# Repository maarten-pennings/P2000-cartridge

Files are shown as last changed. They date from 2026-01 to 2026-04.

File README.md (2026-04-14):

# P2000-cartridge

Making a cartridge for the Philips P2000T.

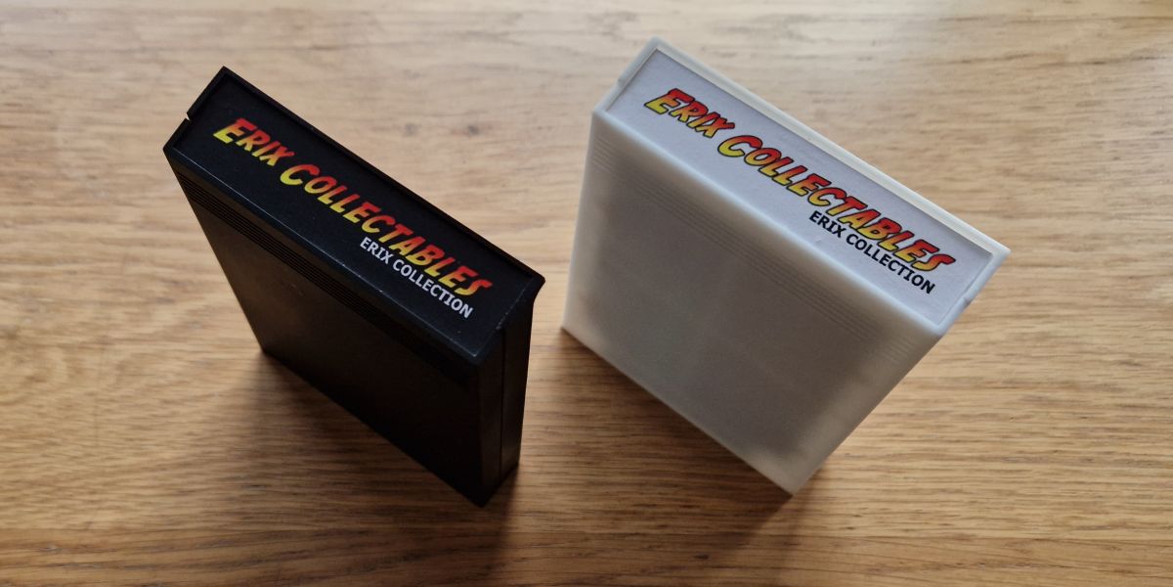
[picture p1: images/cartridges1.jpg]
Cartrdiges


## Introduction

Since I retrieved an old [Philips P2000](https://github.com/maarten-pennings/P2000) from my attic I wanted to make a cartridge myself. 
I help repairing retro computers at [Erix Collectables](https://www.erixcollectables.nl/), and also there we planned 
making a cartridge to facilitate testing and bringing up P2000 mods.

## Analysis

I did some [analysis](analysis.md) coming to the following conclusions:

- Ivo Filot ([Github](https://github.com/ifilot) or [blog](https://philips-p2000t.nl/)) uses
  the [SST39SF0x0](SST39SF010A-SST39SF020A-SST39SF040-Data-Sheet-DS20005022.pdf), 
  it is one of the cheaper solutions, and we have a programmer for it. 
  We will also pick this memory.
- Let's make a modest multi-rom: SST39SF010 - 1 Mbit or 128 kbyte or 8 ROMs. 
  But let's prepare the PCB that they work for the bigger chips too.
- Use PLCC socket; it is smaller than DIL/DIP.
- No reset switch - we don't need it.

## Design

With the analysis phase done, let's make the [PCB](pcb.md).
Design it, manufacture it, test it (tracks), assemble it, and test functionality.
 
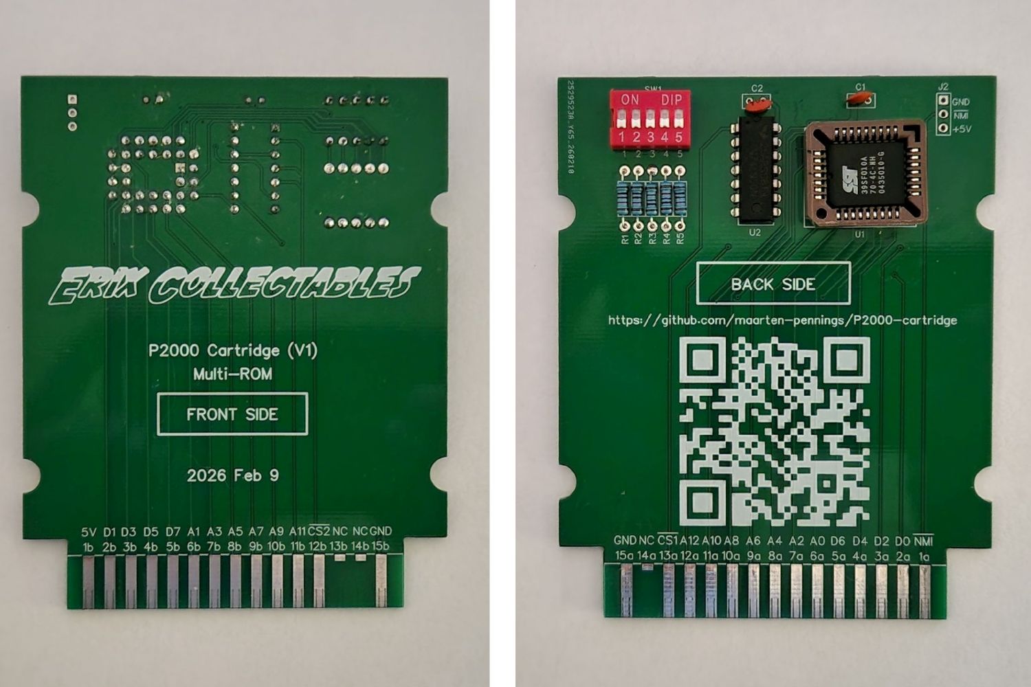
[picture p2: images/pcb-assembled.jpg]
PCB assembled

 
Find all design files (schematics, layout, gerber) in the [pcb](pcb) directory.
.

## Selecting ROMs

Which ROMs to put on the multi-ROM cartridge?
The chosen flash chip 39SF010 has room for 8.

### Stock cartridges

Likely cartridge images are:

- (0) A self-made table of [Contents](roms/myroms).  
  You can press any key to get some references.
- (1) [BASIC NL 1.1](https://github.com/p2000t/software/blob/main/cartridges/BASICNL1.1.bin).  
  The [User manual](https://github.com/p2000t/documentation/blob/main/programming/Gebruiksaanwijzing%20P2000T%20met%20P2305%20Basic%20NL.pdf) is available.
- (2) [Forth](https://github.com/p2000t/software/blob/main/cartridges/Forth.bin).  
  The [User manual](https://github.com/p2000t/documentation/blob/main/programming/Forth30.pdf) or maybe
  the [older version](https://github.com/p2000t/documentation/blob/main/programming/Forth12.pdf).
- (3) [UCSD Pascal](https://github.com/p2000t/software/blob/main/cartridges/UCSD%20Pascal.bin).  
  No documentation. Needs floppy?.
- (4) [Assembler](https://github.com/p2000t/software/blob/main/cartridges/assembler%205.9.bin).  
  No documentation.
- (5) [JWS Disk BASIC](https://github.com/p2000t/software/blob/main/cartridges/JWSBasic.bin).  
  For a P2000 with built-in JWS drive.
  It seems this was developed by Jan-Willem Sparnaaij to enable floppy disks instead of the cassette recorder in BASIC.
  Lot of [tape (?) software](https://github.com/p2000t/software/tree/main/cassettes/JWS).
  The [User manual](https://github.com/p2000t/documentation/blob/main/software/JWS.pdf).
- (6) [ECOL](https://github.com/p2000t/software/blob/main/cartridges/ECOL3.0.bin).  
  The Educational COmputer Language, tagged `FTU/OC ECOL 3.0`.
  This seems to be a sort of simplified Dutch Pascal (?). The only two commands that do
  something are `datum` (irrespective of casing) and `edit`. The `:-` key on the numeric board toggles capslock.
  I wonder if it needs to be accompanied by a tape with an editor, because `edit` complains `Verkeerde band`.
- (7) [Maintenance 2](https://github.com/p2000t/software/blob/main/cartridges/Maintenance%202.bin).  
  A test cartridge. See the Cartridge User Manual in the [Field Support Manual](https://github.com/p2000t/documentation/blob/main/hardware/FieldSupportManual-2.pdf) page 7.1 (72).
  Maybe also the [Maintenance manual](https://github.com/p2000t/documentation/blob/main/hardware/Maintenance.pdf).

List of candidate cartridges can be found on the 
[P2000T Preservation Project](https://github.com/p2000t/software/tree/main/cartridges).

The ones listed here are ["backed up"](roms/stockroms) in this repo.

### Own cartridge: Contents

The proposal is that the first ROM is a table of contents.
I made the [Contents](roms/myroms) ROM myself. 
It is written in assembler, but rather simple: just an LDIR to copy a screen image to the frame buffer.
Press any key to get some references (URLs).

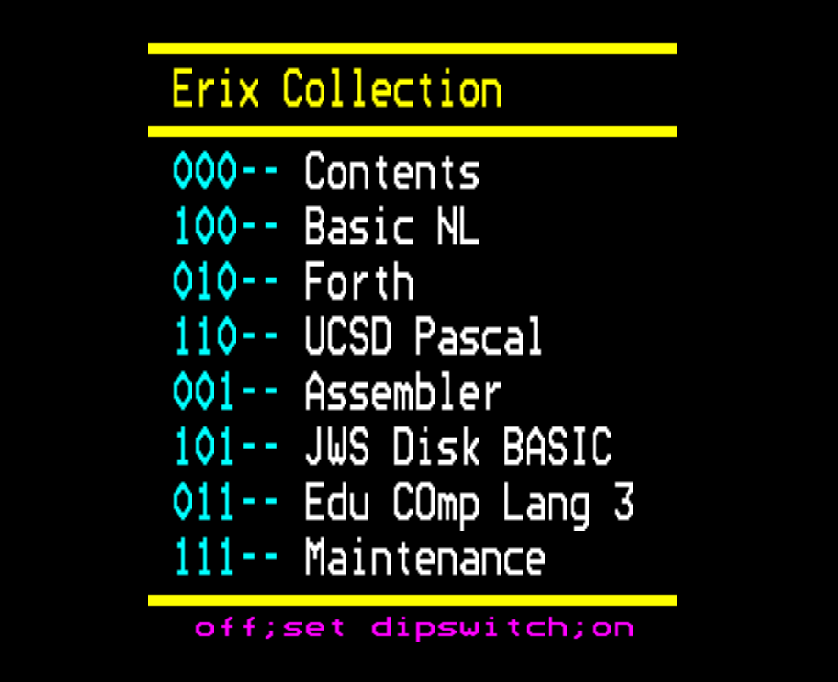
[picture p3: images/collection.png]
Screenshot Collection


### Makefile

The [roms](roms) directory contains a sub directory with the 
[stockroms](roms/stockroms) and a sub directory with [myroms](roms/myroms) 
(the Contents rom). It also contains a [Makefile](roms/Makefile) to compile 
myroms to a `.bin` and convert all `.bin` files (from myroms and from 
stockroms) to flash scripts (`.afp`) - see next section.

## Sub-project: Flash Programmer

We need some tool to flash the `.bin` files to the 39SF0x0 chip.
I don't have one, I could buy one, borrow one or make one.
I went for the latter option an made the "Arduino Flash Programmer".
This topic is described in the [flasher](flasher) directory.

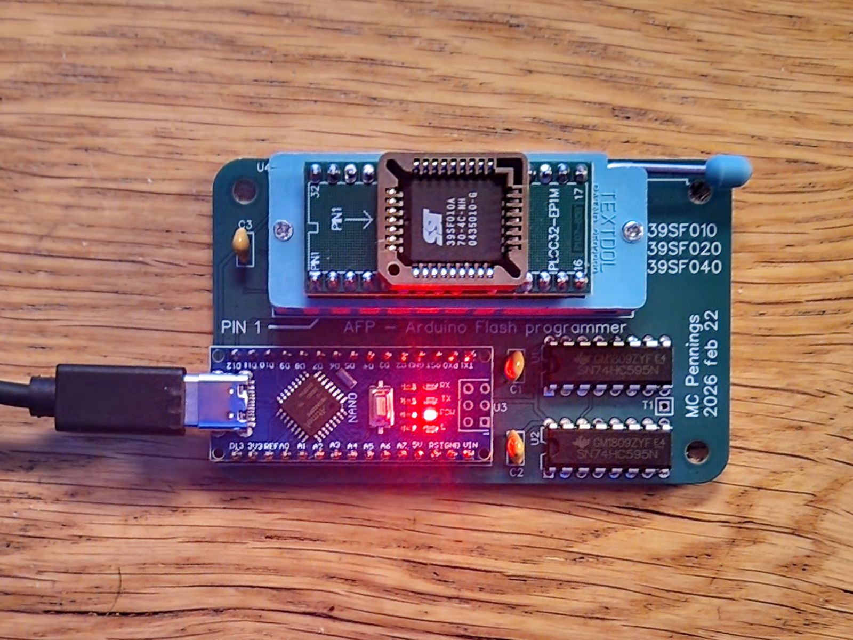
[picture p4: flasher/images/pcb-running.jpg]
AFP


## Casing

One of the last steps is to create a casing.
I wanted it to look as close as possible to the originals.
However, the flash chip in its socket is too high to fit in the original case.
So my case is 1.5mm thicker.
And I have a hole for the dipswitch.

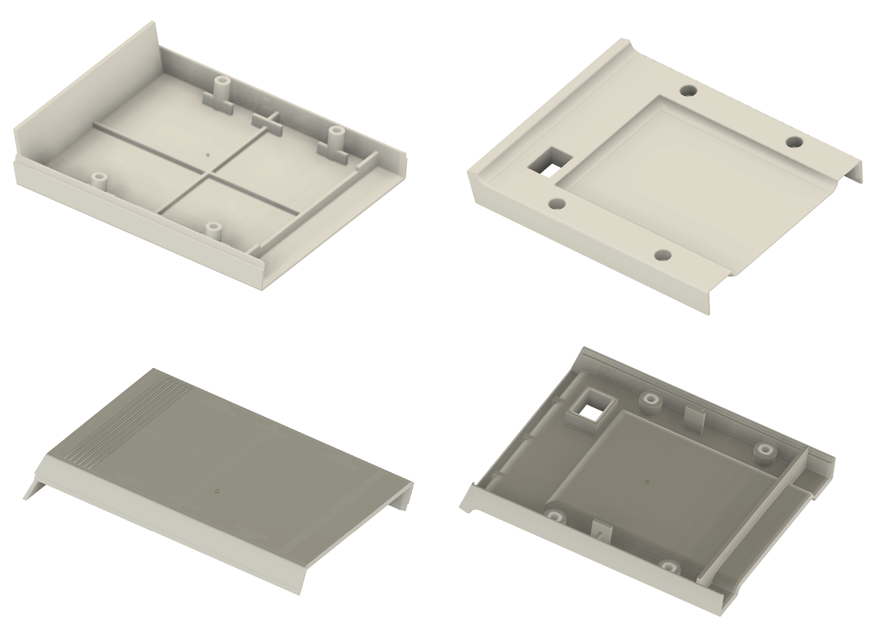
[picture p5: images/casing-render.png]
Casing render
.

I did a 3D print myself. Here mine (left) compared to an original (right).

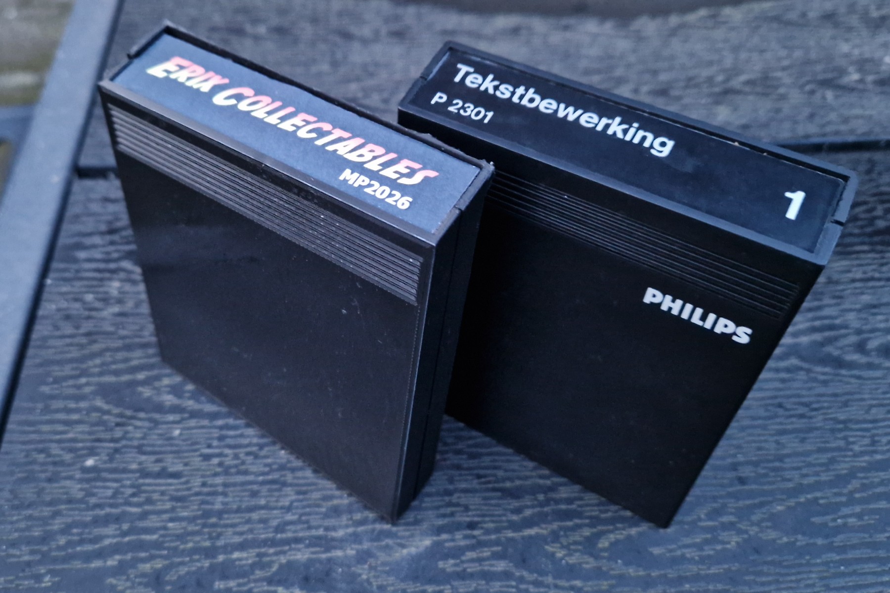
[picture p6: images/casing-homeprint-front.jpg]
Casing home print (front)


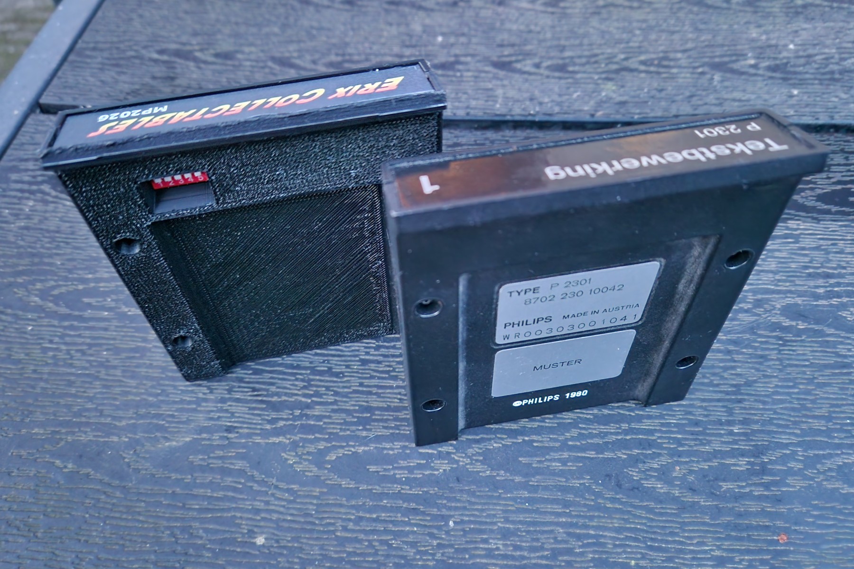
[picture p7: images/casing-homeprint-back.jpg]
Casing home print (back)


Find the stl files in the [case](case) sub directory.

The directory also contains labels: [black](case/label-ErixCollectables-black.png) 
and [white](label-ErixCollectables-white.png) and [sheet](label-ErixCollectables-print.docx).

I also did a 3D print via JLCPCB in white and black.
Those are more detailed with no "support-artifacts".

Cartridges SLA)

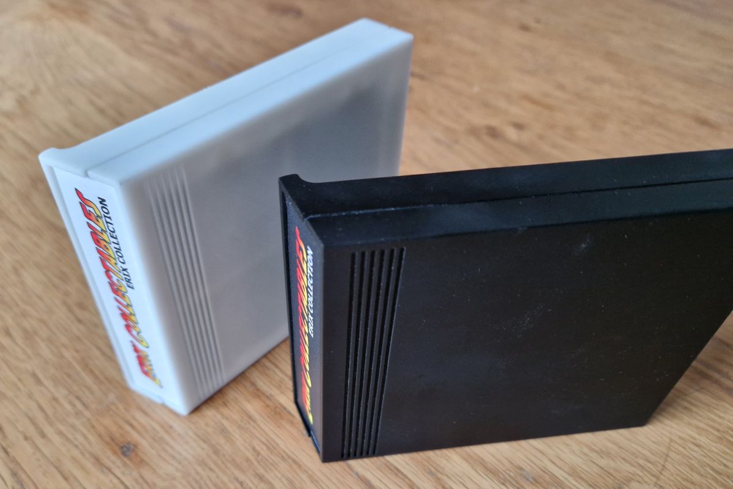
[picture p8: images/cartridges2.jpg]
Cartridges SLA)


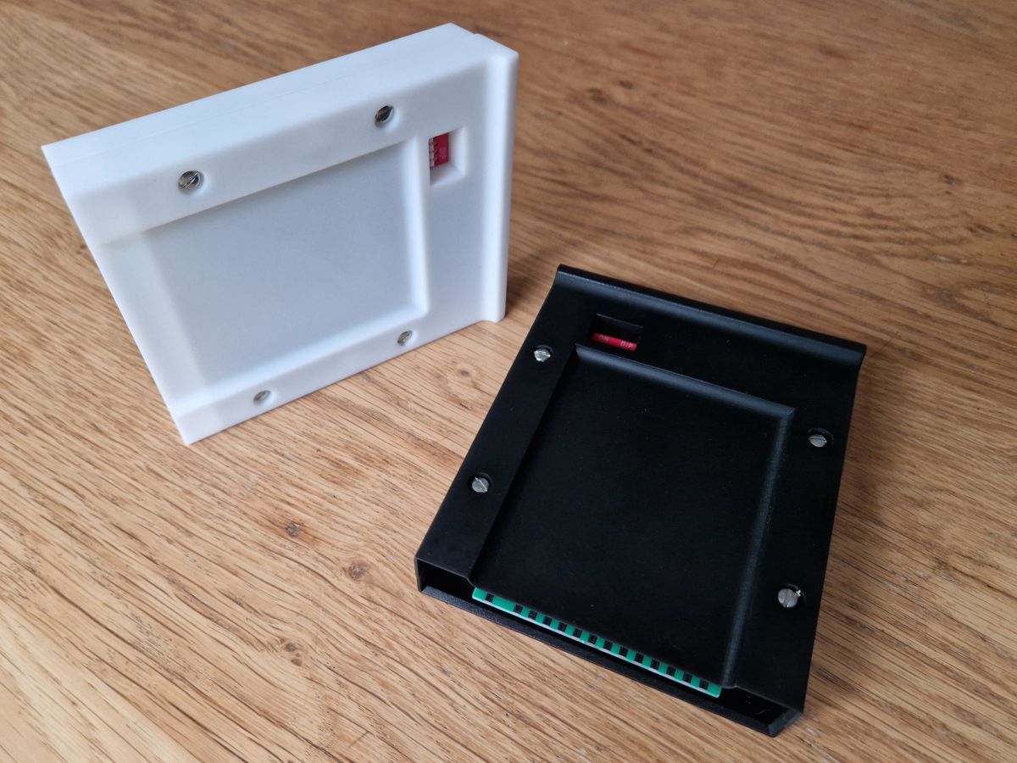
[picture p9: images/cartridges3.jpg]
Cartridges SLA)


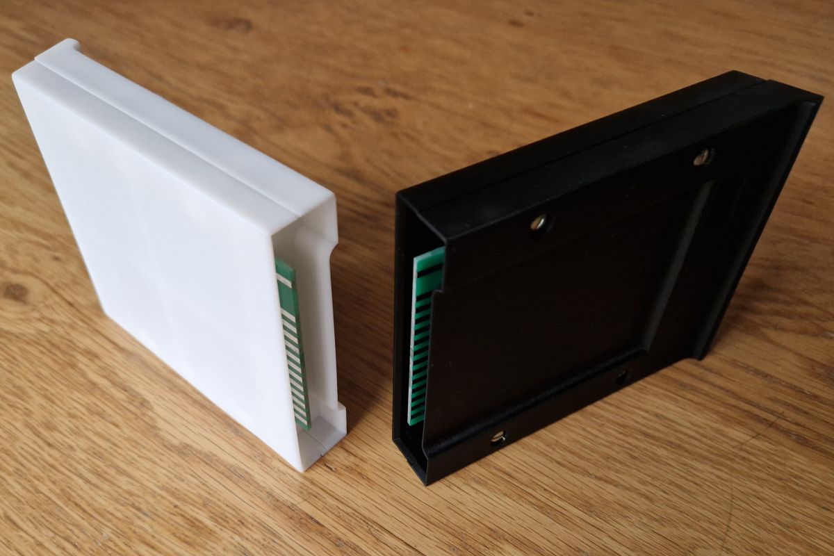
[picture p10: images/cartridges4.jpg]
Cartridges SLA)


## Cost 

Overview of the [cost](cost.md).

(end)

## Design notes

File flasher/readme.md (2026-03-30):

# AFP - Arduino Flash Programmer

Making a tool to program a flash memory.
We use an Arduino Nano with two shift registers to make
the _Arduino Flash Programmer_.

## Prototype

The concept is inspired by [slu4coder's project on GitHub](https://github.com/slu4coder/SST39SF010-FLASH-Programmer).
This is my version of the schematics.

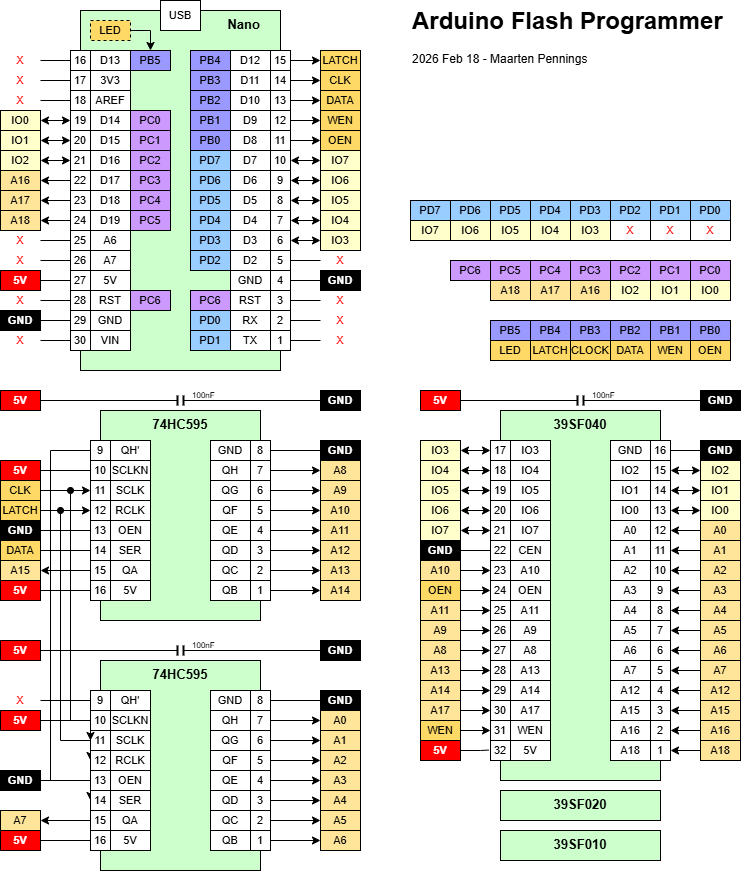
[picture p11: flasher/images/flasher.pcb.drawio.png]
AFP schematics


I tested this on a breadboard

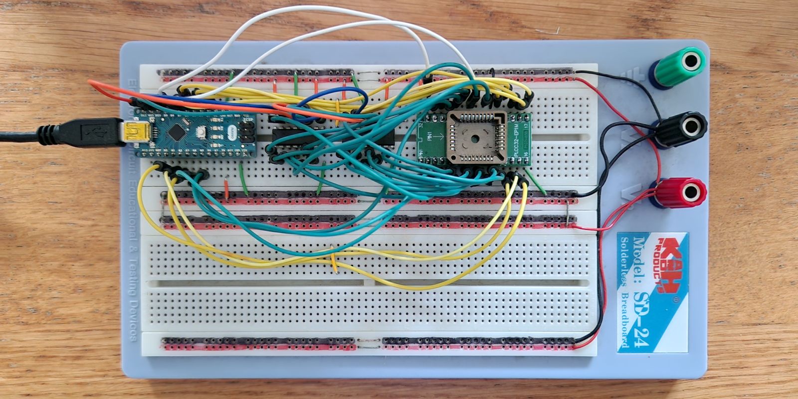
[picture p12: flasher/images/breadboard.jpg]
AFP on breadboard


I quickly found out that I need a tool to get the flash chip 
out of its socket.

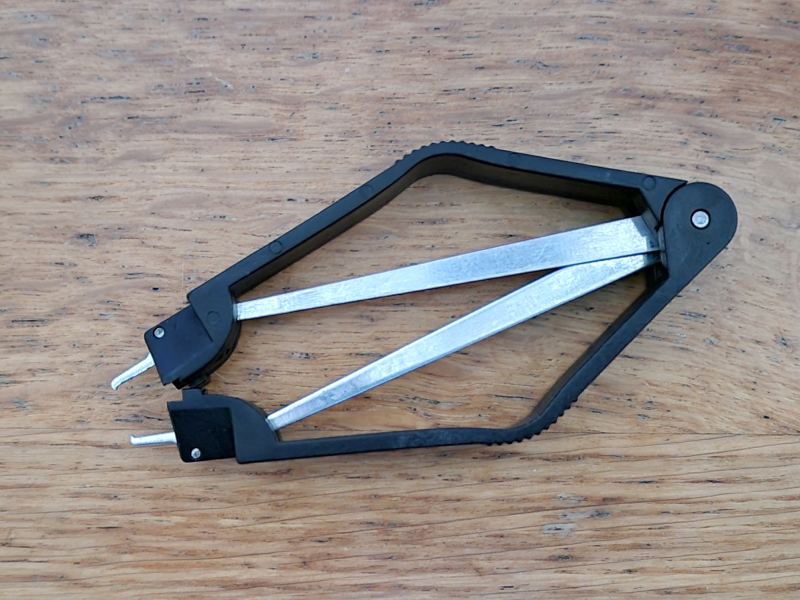
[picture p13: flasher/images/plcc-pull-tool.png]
PLCC IC pull tool


## AFP PCB 

All design files for the PCB are stored in the [pcb](pcb) directory.

### Schematics

I designed the PCB schematics in [EasyEda](https://easyeda.com).
The schematics are available in [pdf](pcb/AFP-schem.pdf) and 
as EasyEda [json](pcb/AFP-schem.json) source.

### Layout

Also the PCB layout I did in [EasyEda](https://easyeda.com).
The layout is available as two pdfs [front](pcb/AFP-pcb-front.pdf) and [back](pcb/AFP-pcb-back.pdf),
and also as EasyEda [json](pcb/AFP-pcb.json) source.

### Gerber

For ordering at [jlcpcb](https://jlcpcb.com) I created a gerber file.
The final [gerber](pcb/AFP-gerber.zip) is also available in this repo.

### PCB render 

The render of the PCB.

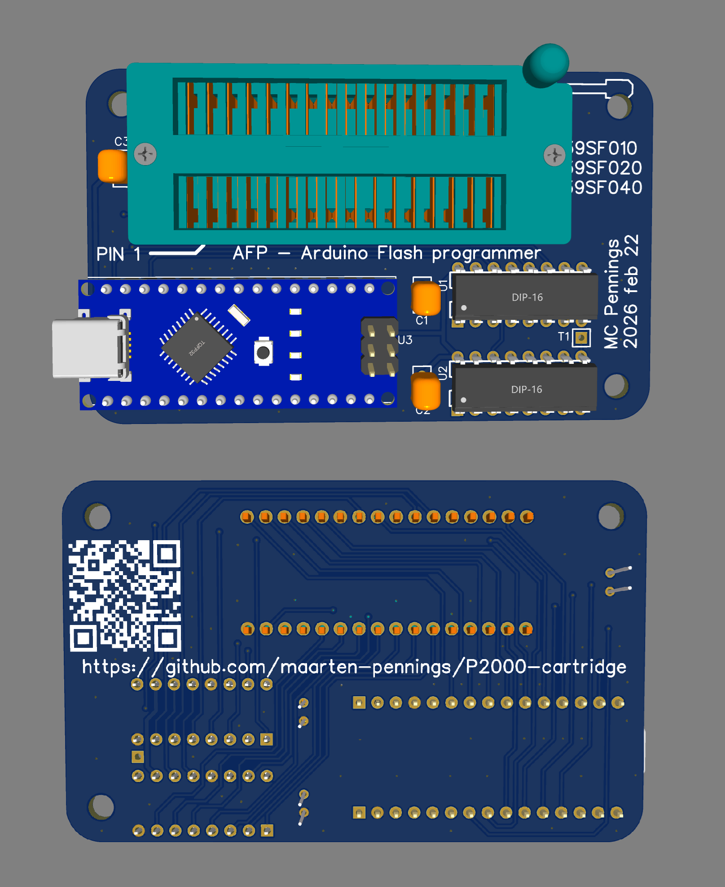
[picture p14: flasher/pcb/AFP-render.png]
PCB render


### PCBs

I ordered at 2026-02-22 and 2026-03-04 the PCBs arrived at my home.

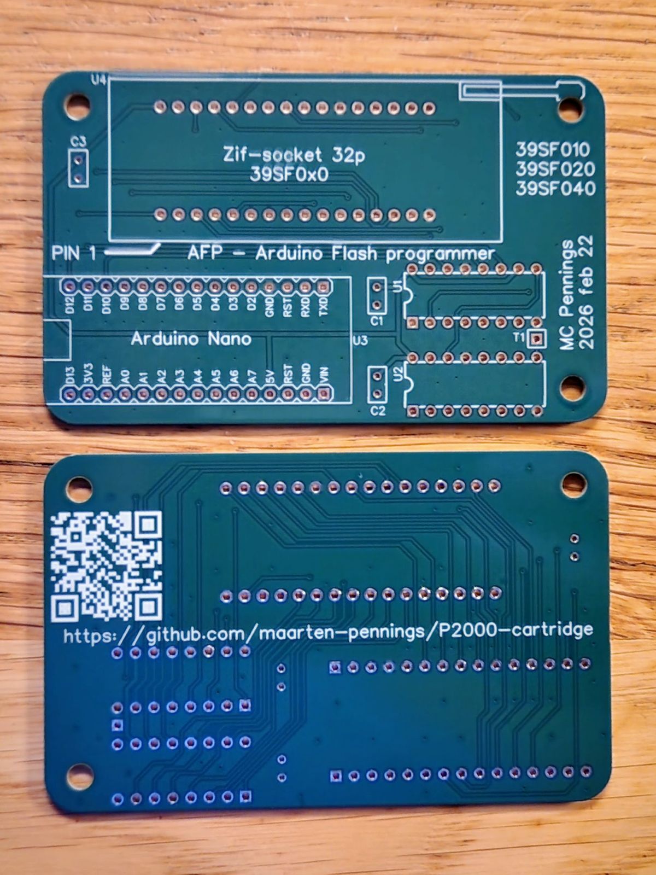
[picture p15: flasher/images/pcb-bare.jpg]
Bare PCB


### Assembly 

After mounting the two ICs, 3 caps, the Arduino Nano and ZIF socket,
the PCB was ready.

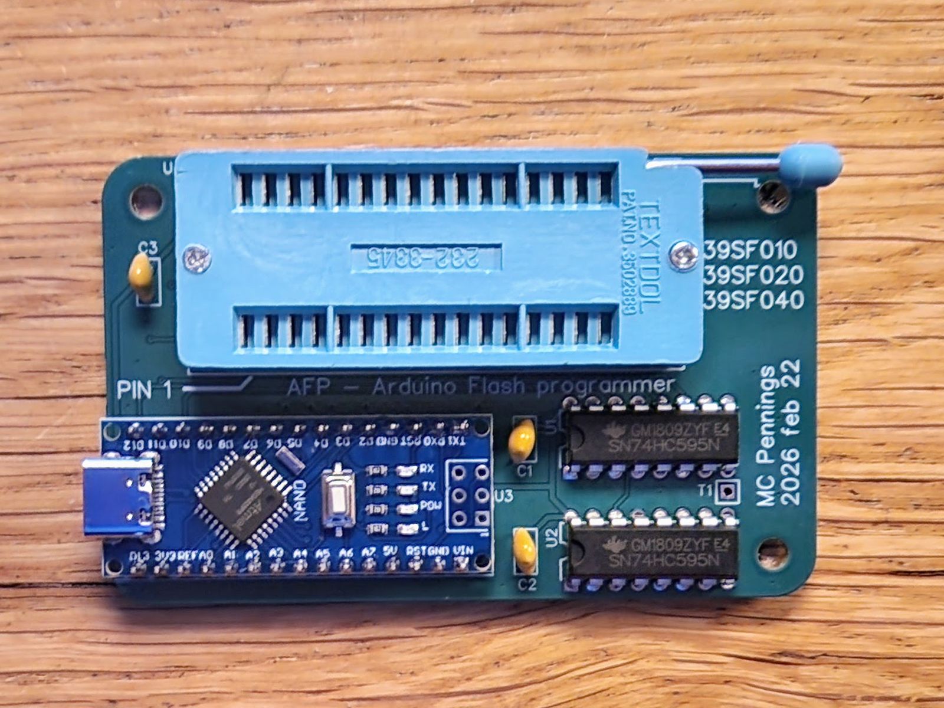
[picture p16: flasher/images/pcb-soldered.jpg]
Soldered PCB


### Firmware

The [AFP firmware](afp) shall be compiled with the 
[Arduino IDE](https://www.arduino.cc/en/software)
and flashed to the Nano.

### Final product

I use an adapter board (here mounted in the ZIF socket) to convert DIL to PLCC.
The adapter board itself contains the PLCC socket (here filled with an 39SF010.

Running PCB

## AFP Manual

Once the firmware is flashed and the AFP connected to a PC, 
a terminal program needs to be started. Make sure to select 
the correct COM port (see e.g. Device Manager), and configure
the terminal program for 115200,8N1. You could use the 
terminal program built into Arduino.

You should be welcomed with the following banner.

```
      _       ________  _______
     / \     |_   __  ||_   __ \
    / _ \      | |_ \_|  | |__) |
   / ___ \     |  _|     |  ___/
 _/ /   \ \_  _| |_     _| |_
|____| |____||_____|   |_____|
Arduino Flash Programmer - version 1.0a

drv  : init
cmd  : init
cmds : init

Type 'help' for help
>> 
```

The `>>` is the prompt of AFP. 

### help

As suggested, we can type `help` to get a list of commands.

```
>> help
Available commands
echo - echo a message (or en/disables echoing)
erase - erase (sector of) the flash
flash - view and control flash size
help - gives help (try 'help help')
info - application and cpu info
read - read flash contents
write - write bytes to flash
```

Help on help explains that commands and sub commands may be shortened.

```
>> help help
SYNTAX: help
- lists all commands
SYNTAX: help <cmd>
- gives detailed help on command <cmd>
NOTES:
- all commands may be shortened, for example 'help', 'hel', 'he', 'h'
- all sub commands may be shortened, for example 'help help' to 'help h'
- normal prompt is >>, other prompt indicates streaming mode
- commands may be suffixed with a comment starting with //
- some commands support a @ as prefix; it suppresses output of that command
```

### echo and info

The `echo` command prints user supplied messages back. 
Give `help echo` if you want to know details.
We skip it here.

Another command we do not further discuss is `info`.

```
>> info
name   : Arduino Flash Programmer
version: 1.0b
author : Maarten Pennings
date   : 2026 mar 20
voltage: 4634 mV
cpufreq: 16000000 Hz
uartbuf: 64 bytes
```

### erase 

A more interesting command is `erase`.
Note that for safety reasons this can not be shortened.

```
>> help erase
SYNTAX: erase
- shows which sectors are empty or in use
SYNTAX: erase <addr>
- erases (ie fill with 0xFF) the sector indicated by <addr>
- when <addr> has form 'all', the whole chip (all sectors) is erased
- when <addr> has form 's<hex>' (sector) that sector is erased
- when <addr> has form 'r<hex>' (rom) all sectors of that rom are erased
NOTE:
- <hex> is in hex
- a sector (4096 bytes) is the unit of erase of the flash chip
- a rom consists of <rom> sectors, the unit of use (eg ROM cartridge)
- <rom> is set with the 'flash' command
- for added safety 'erase' command can not be abbreviated
```

It allows us to pass what to erase: typically a sector (4 kbyte),
or a "rom" (a group of 4 sectors), or "all" sectors. 

Note that the term _erase_ in the context of flash memories writes 0xFF 
to all locations in one _sector_. That is typical for flash memories: erase 
is per sector. Once a sector is erased to 0xFF, writes to bytes 
are allowed; they can only change 1's to 0's.

A nice feature of the `erase` command is to run it without arguments, it
then lists which sectors are "empty", that is, (still) 
completely filled with 0xFF.

If we run this on a memory already programmed with "our" 
stock image, we get this overview.

```
>> erase
rom sectors addresses    state-of-sectors:empty/inuse
R00 S00-S03 00000-03fff:  inuse    -      -      -  
R01 S04-S07 04000-07fff:  inuse  inuse  inuse  inuse
R02 S08-S0b 08000-0bfff:  inuse  inuse  inuse    -  
R03 S0c-S0f 0c000-0ffff:  inuse  inuse  inuse  inuse
R04 S10-S13 10000-13fff:  inuse  inuse  inuse  inuse
R05 S14-S17 14000-17fff:  inuse  inuse  inuse  inuse
R06 S18-S1b 18000-1bfff:  inuse  inuse  inuse  inuse
R07 S1c-S1f 1c000-1ffff:  inuse  inuse  inuse  inuse
clusters: empty 4 inuse 28
```

This tells us that rom 0 (sectors 0-3) contains a small program
(max 4k): the upper 3 sectors are still empty.

It also tells us that the third rom (sectors 8, 9, 10 and 11) 
only uses 3 sectors, not 4.

### flash

The AFP (firmware and PCB) supports three memory chips: 
39SF010 (128k), 39SF020 (256k) and 39SF040 (512k).
They have the same footprint, the smaller chips just 
ignore 2 or 1 address line.

With the flash command, we tell AFP what we use.
There is an auto detect.

```
>> flash chip auto
manid BF: Microchip/SST
devid B5: 39SF010 (1 Mbit = 128 kbyte)
chip size: 128 kbyte (32 sectors) (8 roms)
``` 

This command also allows setting the "rom" size.
This is a pure _software_ feature. 
All addresses entered are either a hex number (actual address), 
or an `S` followed by a hex number (the hex number is the sector number, 
the actual address is found by multiplying by 4k), or an 
`R` followed by a hex number (the hex number is the rom number).
How many sectors a rom is can be set with `flash rom`.

```
>> flash rom 16
rom  size: 16 kbyte (4 sectors)
```

Here we set it to 16 kbytes, the size of P2000 ROMs.
This happens to be the default of AFP anyhow.

### read

The read command needs a starting address and a size.
As starting address we can pass an address, sector number,
or rom number.

The following reads target the same address with these three options.

```
>> read r3 20
R03 S0c 0c000: 5c 00 00 00 00 00 00 00  00 00 00 00 00 00 00 e9
R03 S0c 0c010: 18 4d 0c 00 5e 14 0d 81  00 00 00 00 00 00 00 00
>> read s0c 20
R03 S0c 0c000: 5c 00 00 00 00 00 00 00  00 00 00 00 00 00 00 e9
R03 S0c 0c010: 18 4d 0c 00 5e 14 0d 81  00 00 00 00 00 00 00 00
>> read c000 20
R03 S0c 0c000: 5c 00 00 00 00 00 00 00  00 00 00 00 00 00 00 e9
R03 S0c 0c010: 18 4d 0c 00 5e 14 0d 81  00 00 00 00 00 00 00 00
```

When not specifying the size, a whole "page" is printed (256 bytes).
When not specifying an address the read continues 
where the previous read stopped.

### write

After `erase` the most important command is `write`.
We pass it an address (again three flavors are supported:
address, sector, rom) followed by the data bytes. This command 
supports streaming mode: by passing `*` as data byte streaming 
mode is toggled. When streaming mode is enabled, an end of line 
(new line) does not terminate the write command. It just continues 
on the next line, the streaming prompt will show the address.

As a non-typical example see streaming mode in action.

```
>> read s3 20
R00 S03 03000: ff ff ff ff ff ff ff ff  ff ff ff ff ff ff ff ff
R00 S03 03010: ff ff ff ff ff ff ff ff  ff ff ff ff ff ff ff ff
>> write s3 11 22 33 * 44
w03004>> 55 66 
w03006>> 77 * 88
>> read s3 20
R00 S03 03000: 11 22 33 44 55 66 77 88  ff ff ff ff ff ff ff ff
R00 S03 03010: ff ff ff ff ff ff ff ff  ff ff ff ff ff ff ff ff
```

For a more typical example of streaming mode see the afp files 
generated by the [Makefile](../roms/Makefile).
You can find afp files by going to 
[GitHub actions dashboard](https://github.com/maarten-pennings/P2000-cartridge/actions) 
click top one, and on the next screen at the bottom, download and open the build results 
called "roms.zip".

It might be good to know that the write command maintains 
error statistics. These can be reset.

```
>> write stats clear
cleared
>> write s3 aa bb
>> write stats
bytes written 2
write errors  2
elapsed time  25342 ms
```

Both write fail because sector s3 was just written with 
`11 22`, so a write of `aa bb` without an erase fails.

## Script

In the sub-directory [roms](../roms) you find all the roms 
(binary files), and (Python) programs that result in a script
(sequence of write commands) for the AFP tool.

There are several tools in the flow:

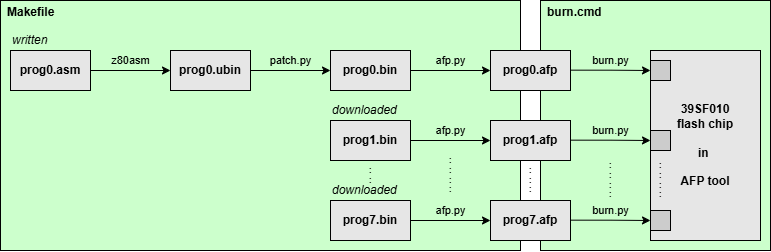
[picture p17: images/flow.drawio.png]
Flow overview


## Test rig

One out of the 10 cartridges I made is not working.
It is cartridge nr 9; when I plug it into a P2000 it is not recognized by the P2000.
The P2000 behaves as if no cartridge is plugged in, which is probably concluded when the chcecksum has a mismatch.
I swapped the 39SF010 memory chip with another cartridge, but nr 9 keeps failing (and the other cartridge kept working), so the PCB seems to be the issue.

I bought an edge connector and hooked it up to an Arduino.
Basically I made a test rig with an architecture similar to the AFP board design.
I read the ROM from cartridge 9 and this proved ok (read back what I flashed).

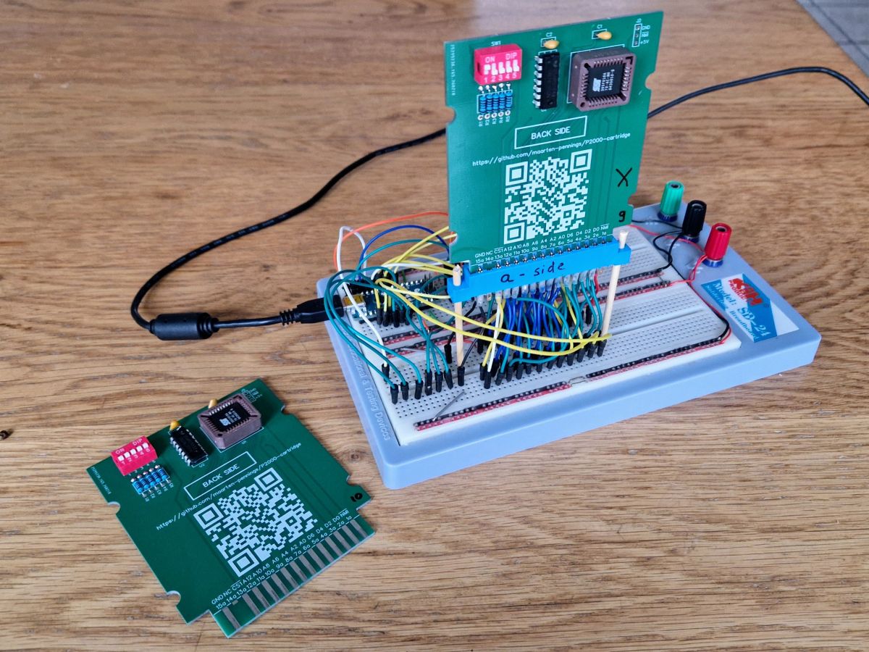
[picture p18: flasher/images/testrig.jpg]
Test rig


I'm puzzled why the PCB is not working.

(end)

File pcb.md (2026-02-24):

# P2000-cartridge - PCB design

With the analysis phase done, let's make the PCB.
Design it, manufacture it, assemble it, and test it.

## Schematics

I designed the PCB schematics in [EasyEda](https://easyeda.com).
They are available in [pdf](pcb/P2000Cartridge-schem.pdf) and 
as EasyEda [json](pcb/P2000Cartridge-schem.json) source.

## Layout

Also the PCB layout I did in [EasyEda](https://easyeda.com).
The layout is available as two pdfs [front](pcb/P2000Cartridge-pcb-front.pdf) 
and [back](pcb/P2000Cartridge-pcb-back.pdf),
and also as EasyEda [json](pcb/P2000Cartridge-pcb.json) source.

I double checked the socket since I don't have it yet physically.
Warning, the socket diagram is the pin-out from the front side of the PCB 
("bottom view").

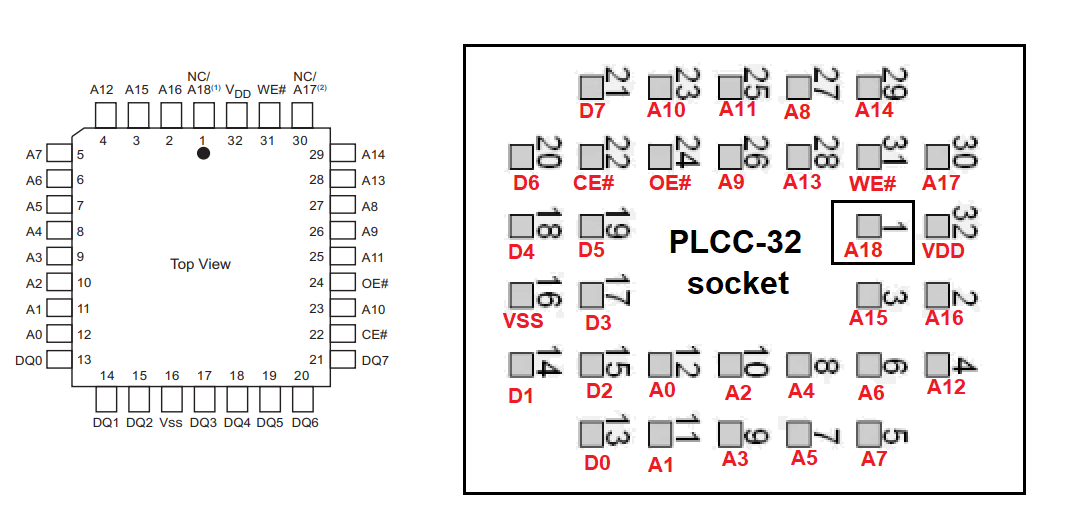
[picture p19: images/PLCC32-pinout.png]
socket
 

## Gerber

For ordering at [jlcpcb](https://jlcpcb.com) I created a gerber file.
The final [gerber](pcb/P2000Cartridge-gerber.zip) is also available in this repo.

The render of the PCB.

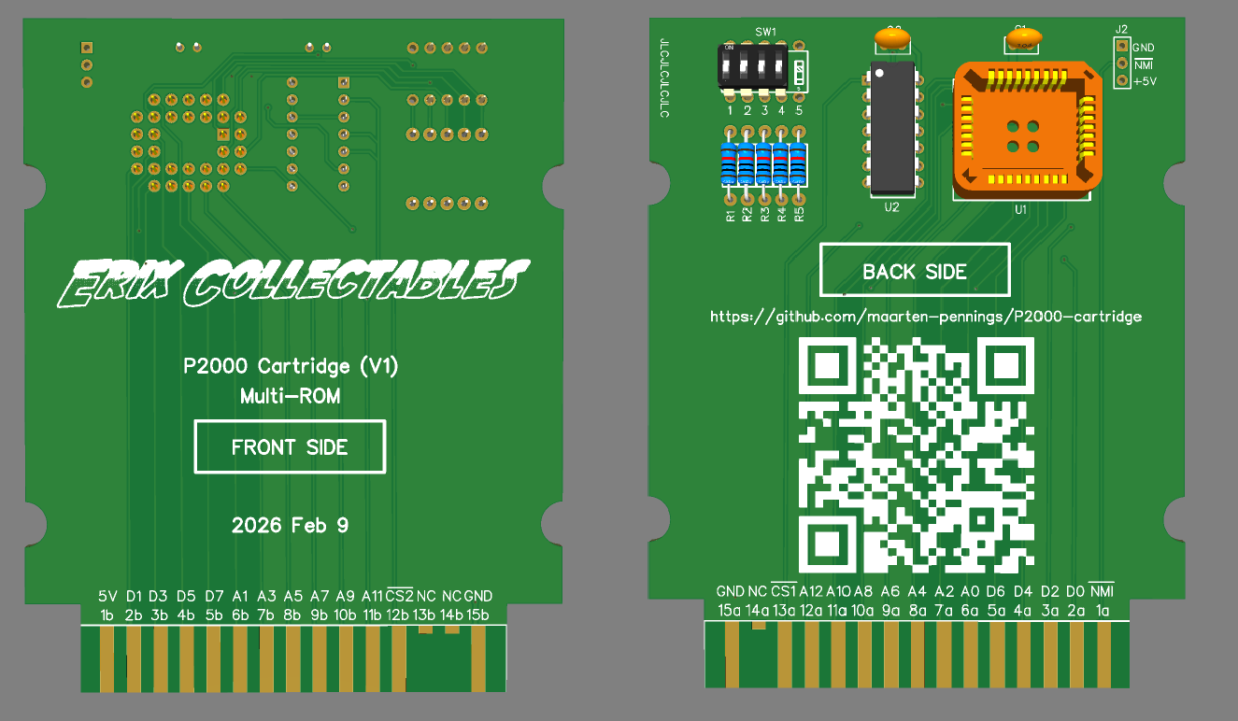
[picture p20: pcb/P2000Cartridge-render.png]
PCB render


## Bare PCBs

I ordered at 2026-02-09 and 2026-02-19 the PCBs arrived at my home.
In 10 days, that is not bad.

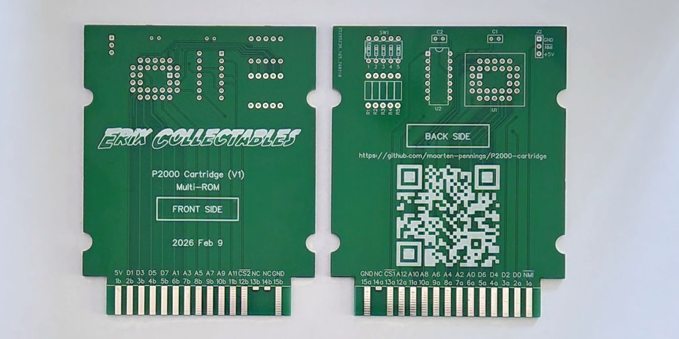
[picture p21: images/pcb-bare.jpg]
PCB bare


I did a quick "continuity" test; are all pads going where I think they 
need to go.

For a moment I believed I mirrored the flash socket.
That was due to the diagram from when I checked the [layout](#layout).
That diagram is mirrored, since I checked it in EasyEda with the front 
side visible. Now I was measuring at the backside.

## Assembly

Next step is assembly. That was easy. Just one socket, one DIL IC, 
2 capacitors, 5 resistors and a dip-switch. The copper pours on the 
PCB caused some soldering issues: the pad don't get hot enough.

PCB assembled

## Possible improvements

I probably should
- have put a pin-one marking on the PCB (for the flash socket);
- placed the flash socket even higher to make it fit in a standard 
  P2000 cartridge (the socket is the thickest, up in the cartridge 
  there is more depth).

I am still bothered that the dip-switch footprint has bit 1 in the right-most 
position instead of the left-most: I want my bits big-endian.

(end)

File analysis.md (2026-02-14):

# P2000-cartridge - Analysis

This file documents the analysis I did for [making a cartridge](README.md) for the Philips P2000T.

## Make a single or multi-rom cartridge?

A cartridge either occupies 8 kB or 16 kB in the memory map of the P2000 (see map below).
Modern EEPROMs are typically much bigger, for example an 512 kB EEPROM could store 32 cartridge images of each 16 kB.
The alternative is using a smaller ROM or simply not using the extra memory in the EEPROM.

Technically a multi-ROM sounds interesting. Down-sides include: not very retro-like,
not-so robust dip switches needed, need sticker with e.g. 32 entries, don't switch while powered,
do we have enough ROMs to make sense in one EEPROM.

There is a great [GitHiub](https://github.com/ifilot) account from Ivo Filot showing both options.

- ["simple" ie single](https://github.com/ifilot/p2000t-simple-cartridge)

- [Several multi](https://github.com/ifilot/p2000t-cartridges)

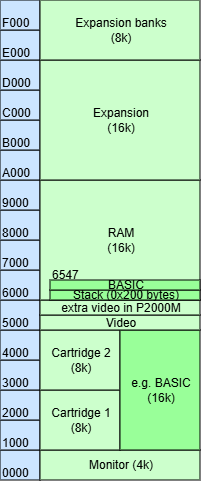
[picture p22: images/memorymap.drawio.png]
P2000T Memory map


## Which EEPROM chip to use?

Again, looking at Ivo's GitHub, there are two likely candidates. 

- The SST39SFxxx series.  

  | Type       |  bit |     byte      | ROMs | dip switches | link    |
  |:-----------|-----:|:-------------:|-----:|:------------:|:--------|
  | SST39SF010 | 1 Mb | ⅛ MB = 128 kB |    8 |      3       |[🔗](https://ww1.microchip.com/downloads/aemDocuments/documents/MPD/ProductDocuments/DataSheets/SST39SF010A-SST39SF020A-SST39SF040-Data-Sheet-DS20005022.pdf) |
  | SST39SF020 | 2 Mb | ¼ MB = 256 kB |   16 |      4       | idem    |
  | SST39SF040 | 4 Mb | ½ MB = 512 kB |   32 |      5       | idem    |

- The W27Cxxx or W28Cxxx series.

  The W27Cxxx seems to be for EPROMs (one E), they are erased by exposure to a UV (ultraviolet) light. Programming typically requires a higher voltage supply (e.g., 12.5V or 13V Vpp).
  The W28Cxxx seems to be for EEPROMs (two Es), they are electrically erasable and programmable.
  However I have an 27C256 without a "window", so I'm not sure about this.
  
  I have experience with the W28C64, Ivo [mentions](https://github.com/ifilot/p2000t-cartridges?tab=readme-ov-file#4-x-16kib-tht-w27c512-64-kib-rom) the w27c512.

  | Type       |    bit |    byte | ROMs | dip switches | link    |
  |:-----------|-------:|:-------:|-----:|:------------:|:--------|
  | W28C64     |  64 kb |    8 kB |    ½ |    -1   😊   | [🔗](https://ww1.microchip.com/downloads/en/devicedoc/11003L.pdf) |
  | W28C128    | 128 kb |   16 kB |    1 |     0        | [🔗](https://ww1.microchip.com/downloads/aemDocuments/documents/MPD/ProductDocuments/DataSheets/AT28C256-Industrial-Grade-256-Kbit-Paged-Parallel-EEPROM-Data-Sheet-DS2000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) |
  | W27C256    | 256 kb |   32 kB |    2 |     1        | [🔗](https://ww1.microchip.com/downloads/aemDocuments/documents/OTH/ProductDocuments/DataSheets/11001N.pdf) |
  | W27C512    | 512 kb |   64 kB |    4 |     2        | [🔗](https://ww1.microchip.com/downloads/en/DeviceDoc/doc0015.pdf) |

## Which EEPROM package?

Both chips come in two packages.

- PLCC stands for Plastic Leaded Chip Carrier.

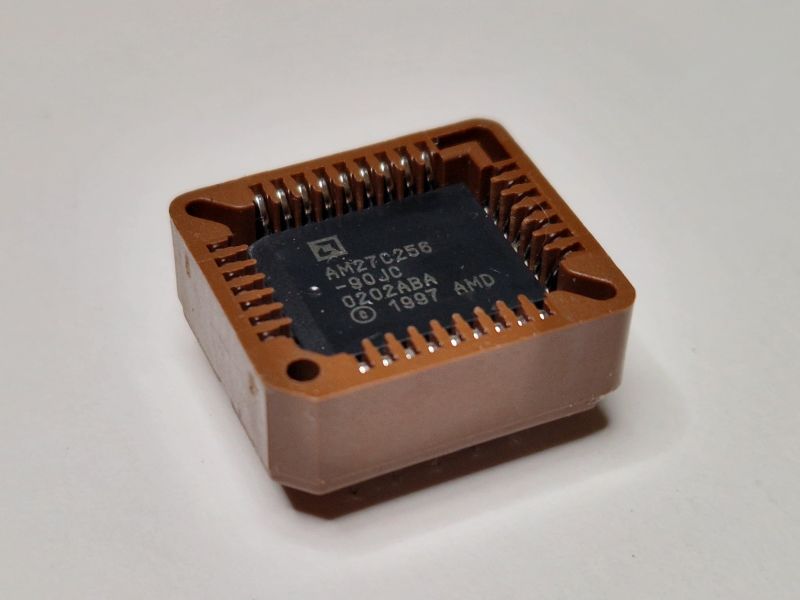
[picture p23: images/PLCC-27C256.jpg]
PLCC
  

- DIL or DIP stands for Dual In-line (or Dual In-line Package/Packaging).

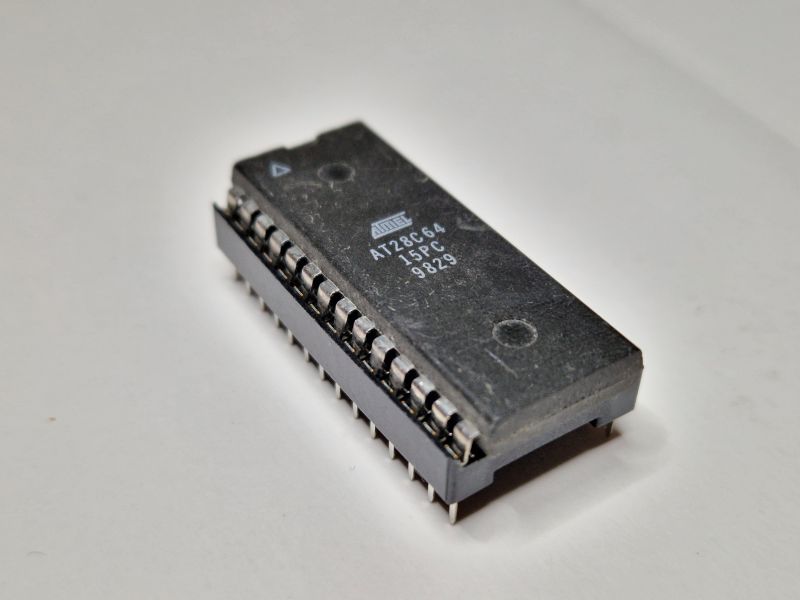
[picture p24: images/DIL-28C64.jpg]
DIL
  
  
There is a slight height difference of 0.6mm when socketed:
the PLCC is 7.8mm and the DIL is 8.4mmm.

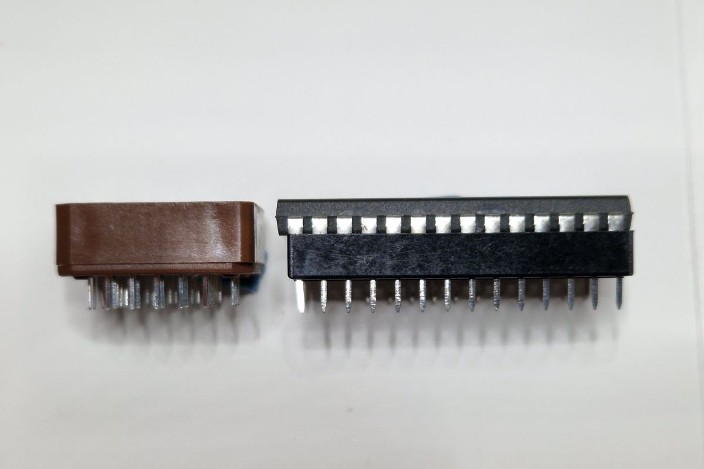
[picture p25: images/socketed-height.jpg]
Socketed height


## With or without socket?

"With" socket allows us to reflash - e.g. when a first flash somehow failed.
Of course we could have one cartridge with socket ("for development") and solder 
all the rest (for "use").

Why is this even a question?
Not the extra money for the socket, but the increased height: 
the P2000 cartridges do not leave room for sockets:
"the PLCC is 7.8mm and the DIL is 8.4mmm", both more than 7.2.

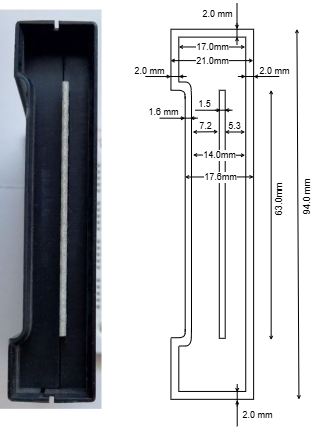
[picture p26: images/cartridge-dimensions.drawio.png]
Cartridge dimensions


We could put the socketed chip in the top of the cartridge.
See here some photos of a mock-up.

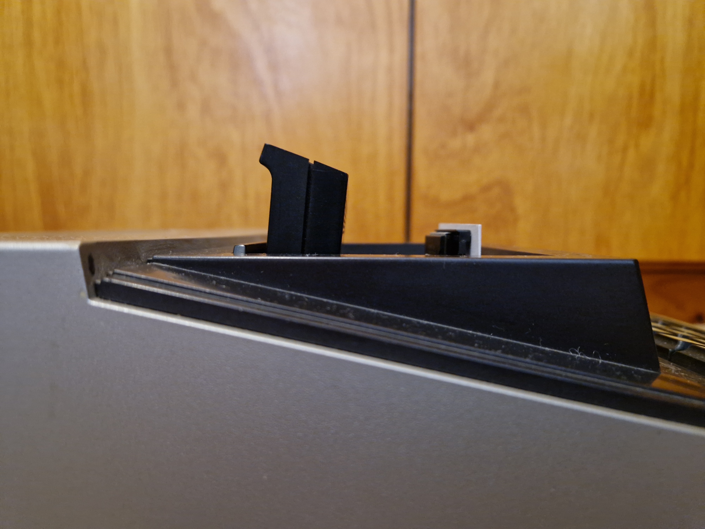
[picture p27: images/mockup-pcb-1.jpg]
Mockup PCB


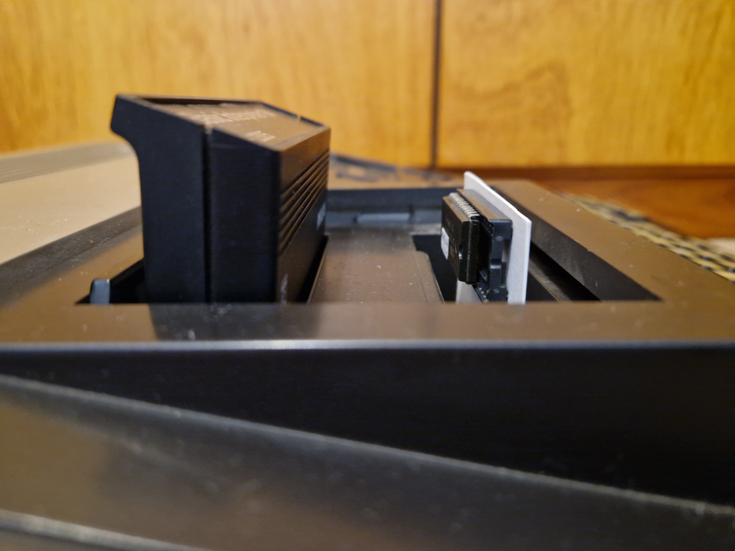
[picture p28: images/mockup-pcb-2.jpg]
Mockup PCB


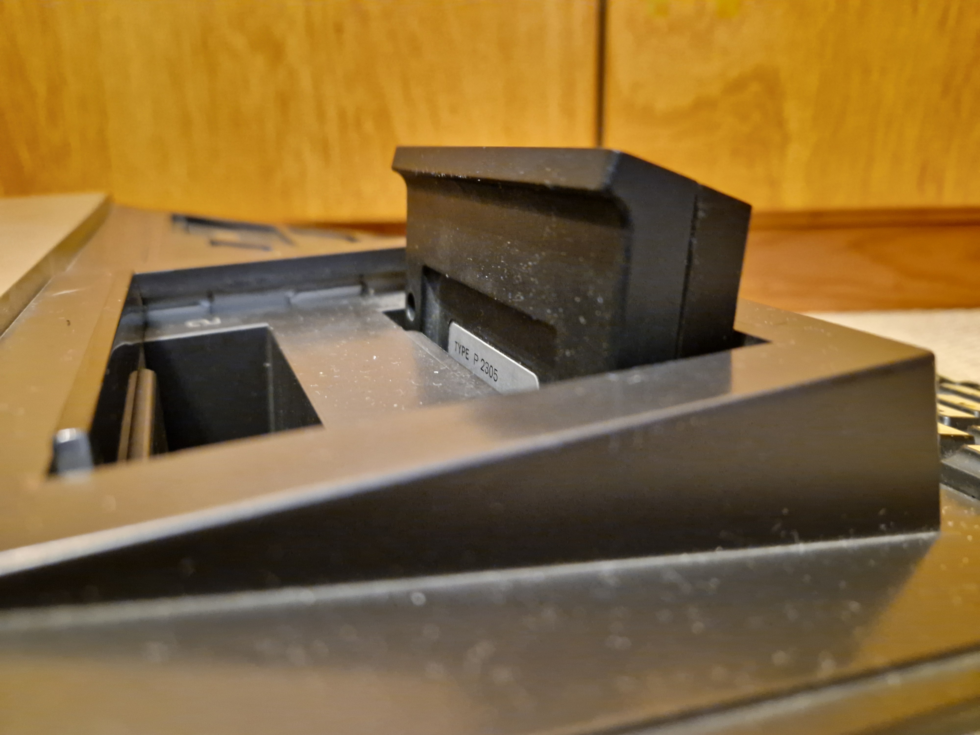
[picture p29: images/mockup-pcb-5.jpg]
Mockup PCB


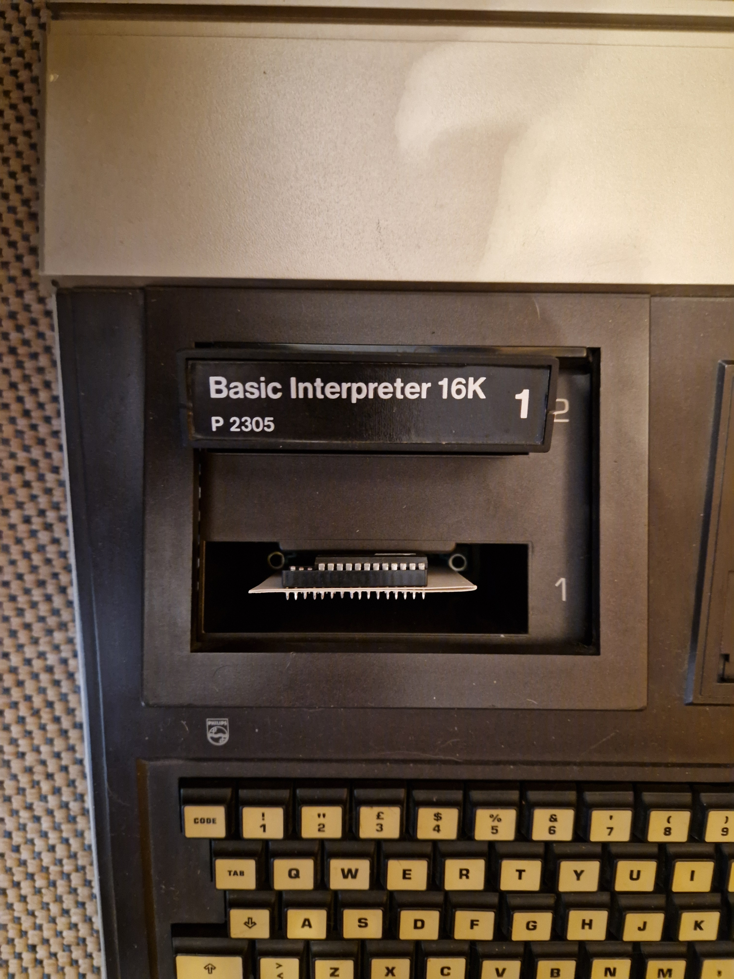
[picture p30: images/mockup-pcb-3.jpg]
Mockup PCB


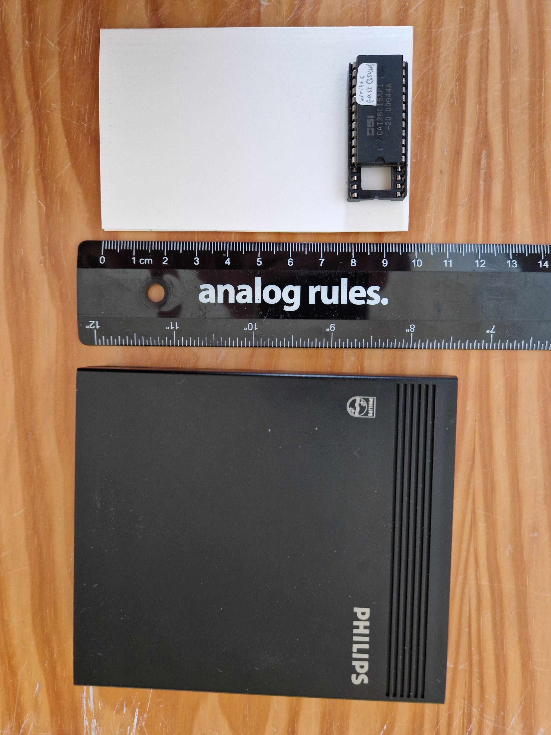
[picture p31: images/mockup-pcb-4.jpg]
Mockup PCB


## How to program the EEPROM?

I do have a self-made [programmer](https://github.com/maarten-pennings/6502/tree/master/3eeprom#3a2-the-programmer).
Unfortunately, it only supports 28C16 and 28C64; we would now need at least one notch up: 28C128.

I do not yet have an overview of good programmers, there might be one available with a colleague.

It turns out, colleagues at Erix Collectibles do have a programmer.

## Reset switch?

Do we want a reset switch? Quite complicated schematics.

## Schematics

When we look at Ivo's [27C512](https://github.com/ifilot/p2000t-cartridges?tab=readme-ov-file#4-x-16kib-tht-w27c512-64-kib-rom) solution
it is very similar to the SST39SF040  solution.

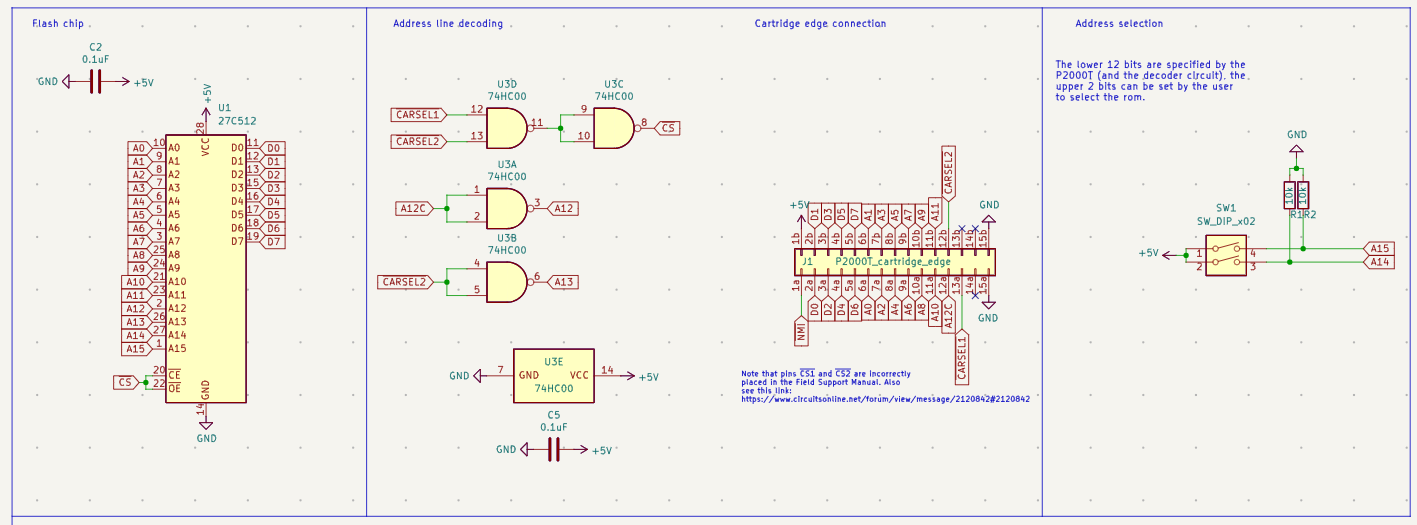
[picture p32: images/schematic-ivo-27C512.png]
Schematics


Source: [click sch file in right pane](https://kicanvas.org/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)

Contents of this design:

- Flash chip with a capacitor.
- Cartridge edge connector.
- Dip switch controlling A14 and A15.
- Address decoding with one quad NAND (with cap).

Explanation of the design:

- Flash chip routes D0..D7 to edge connector.
- Flash chip routes A0..A11 to edge connector.
- Flash chip routes A12 and A13 to address decoding.
- Flash chip routes A14 and A15 to dip switches.

The hardest part is the address decoding.
But I happen to have investigated that [earlier](https://github.com/maarten-pennings/P2000/blob/main/readme.md#addressing).

## Proposal

- Let's go for a modest multi-rom.
- We have a programmer for SST39SF010, Ivo uses it and it is cheaper.
- PLCC is smaller.
- I want to go for with-socket; maybe move the socket to the top of the PCB.
- No reset switch - don't need it.

(end)

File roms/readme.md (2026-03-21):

# P2000-cartridge - Contents ROM

Partly as a proof of concept, partly for branding and partly for documentation,
I decided to make my own _Contents_ ROM. 

GitHub actions dashboard

## Introduction

The idea is that the _Contents_ app can operate as a real cartridge.
A ROM chip filled with this app's binary image should make the P2000 boot-loader accept it.
This means the image should start with the correct header, which includes a matching checksum.
Then the boot-loader will start our app.

The _Contents_ ROM would be the first ROM in our multi ROM cartridge.
We keep this app simple. It should list which other ROMs are stored on the multi ROM.
It is written in assembler, but doesn't do much: it is basically an LDIR instruction to 
copy a prerecorded screen (which is part of the ROM) to the P2000 frame buffer.

It should be noted that the P2000 has a frame buffer that holds 80×25 characters.
This is twice as wide as the physical screen, which is 40×25 characters.
With an `OUT` instruction we can instruct the video chip which column starts on the physical display.

It should also be noted that the P2000 only has a "character buffer", not a "color buffer".
Different colors are created by "switch color" characters that display as a space on the screen.
It does mean that just copying the 2000 bytes is enough.

We use the second screen to shows some URLs, e.g. to this repo or to Erix Collectibles.
Pressing any button will toggle the screens.

## Implementation

For the source file of the Contents ROM, see the [myroms directory](myroms/contents.asm).

Notes

- A cartridge is mapped to 0x1000 in the P2000 memory map. The first line is therefore `org 0x1000`.

- Next comes the 16-byte header. 
  See [P2000 System T&M Reference Manual](https://github.com/p2000t/documentation/blob/main/hardware/P2000%20System%20T%20%26%20M%20Reference%20Manual.pdf).
  Section 4.4.2 on the 51st page describes the header.

  | Address | Field     |  Description     |
  |:--------|:----------|:----------------:|
  | 0x1000  | Signature |        5E        |
  | 0x1001  | ROM size  | lo-byte, hi-byte |
  | 0x1003  | Checksum  | lo-byte, hi-byte |
  | 0x1005  | ROM name  |      8 bytes     |
  | 0x100D  | Version   |      1 byte      |
  | 0x100E  | Reserved  |      2 bytes     |
  
- Next comes `main`, the entry point of our app.
  It  copies two screens of data from the ROM image (label `screens`) to the frame buffer at 0x5000.
  
- Next comes the main `loop`.
  It configures the video chip to show the first screen, and after a key-press the second.
  After another key-press back to the first screen.
  Note that the screen switching is done with `OUT (48),0` respectively `OUT (48),40`. 
  
- Following the main loop are some rudimentary keyboard scan routines.
  
- The assembler file ends with 2000 bytes of string data, representing the two screens.

## Python helpers

There are some Python scripts to process bin files.

### Patch

To compute the checksum for any P2000 ROM image, we have written a python program [`patch`](patch.py).
This reads a `.bin` file - for example ours as produced by the assembler - computes the checksum, and 
overwrites the checksum bytes in the header.

The `patch` script assumes the whole file should be part of the checksum. We have noticed that 
existing commercial ROMs sometimes specify a shorter ROM size (bytes at 0x1001/0x1002).
It is even possible to use a size of 0 (and set the checksum at 0).

### Pad

The generated bin file should not exceed 16 k (the P2000 doesn't allow more).
Typically they are shorter.

Since we want to make a multi ROM, we need to concatenate 8 ROMs into one big one 
and offer that to the flash programmer.

The Python script [`pad`](pad.py) pads a `.bin` file with 0xFF bytes to be exactly 16 k bytes.
It is your choice whether to first run `patch` and then `pad` or the other way around.
The first one boots faster, in the second one, all padding bytes are 
included in the checksum.

> The [ROM](https://ww1.microchip.com/downloads/aemDocuments/documents/MPD/ProductDocuments/DataSheets/SST39SF010A-SST39SF020A-SST39SF040-Data-Sheet-DS20005022.pdf)
> we have chosen can be erased per sector of 4 k bytes. One P2000 ROM exactly matches 4 sectors.
> Furthermore, our [flasher](../flasher) supports erasing individual sectors and it supports
> writing individual sectors (bytes actually).
> As a result, when using our proprietary flasher, there is no need to use `pad`, and we don't.

### AFP

We have written a proprietary flasher, called the AFP or [Arduino Flash Programmer](../flasher).
AFP is a tool made from an Arduino sketch and a Nano; this tool burns flash memories.
AFP has a user interface via the virtual COM port (over USB).
This interface is textual, there is a `read` command, an `erase` command and a `write` command.

The Python [`afp`](afp.py) script converts a `.bin` file to an `.afp` file, a text file with 
commands for the AFP tool. The generated `.afp` file contains one `erase` command for the area 
the binary is mapped to, and one `write` command with (up to) 16 k bytes of data for that area.

The `.afp` file can be sent via the virtual COM port to the AFP tool.

Here is the shortened `contents.afp` file; `R0` denotes an address, the `R` stands for
"ROM" and means that the "units" is 16 k bytes. The actual address is 0×16k=0x00000.
For erase, it also implies a size of 16 k, that is, 4 sectors.

```
erase R0

write R0 *
5e 15 08 6a 9f 4d 50 45  4e 32 30 32 36 00 00 00 
...
20 20 20 20 20 20 20 20  20 20 *
```

### Burn

For each ROM an `.afp` file is generated. This is a text file, which can be sent 
via the virtual COM port to the AFP tool. The problem when sending such an `.afp` file 
to the AFP tool is speed difference: the sender (the PC) is much faster than the micro controller 
in the AFP tool (Nano). The result is that the AFP tool can't keep up, commands get scrambled or lost.

One solution is to use a terminal tool that not only can sent text files, but which can also be
throttled by setting a line delay (of say 10ms per line).

Another solution is to only send the next line when the previous is executed.
The AFP tool signals this by sending a prompt (`>>`) back.

The Python [`burn`](burn.py) script does just that. It sends `.afp` files to the AFP tool, line by line, 
each time waiting for the prompt.

## Makefile

There is a [Makefile](Makefile) that compiles the [assembly source](myroms/contents.asm) to an
unpatched bin file (`.ubin`). Next the Python `patch` script is run. It patches the 
checksum and generates a `.bin` file. You can run this in the [emulator](https://github.com/p2000t/M2000).

The makefile also generates the `.afp` files that can be sent to the [Arduino Flash Programmer](../flasher). 
The makefile not only converts the `contents.bin` to `.afp`, but also seven [stock roms](stockroms).

I develop on Windows, but use WSL to install the Z80 assembler.
This repo also has a workflow to do this every Git push, see the 
[workflow](../.github/workflows/build_contents.yml).

On the [GitHub actions dashboard](https://github.com/maarten-pennings/P2000-cartridge/actions) you see every run. 
Click one, and on the next screen at the bottom, download the build results called "roms.zip".

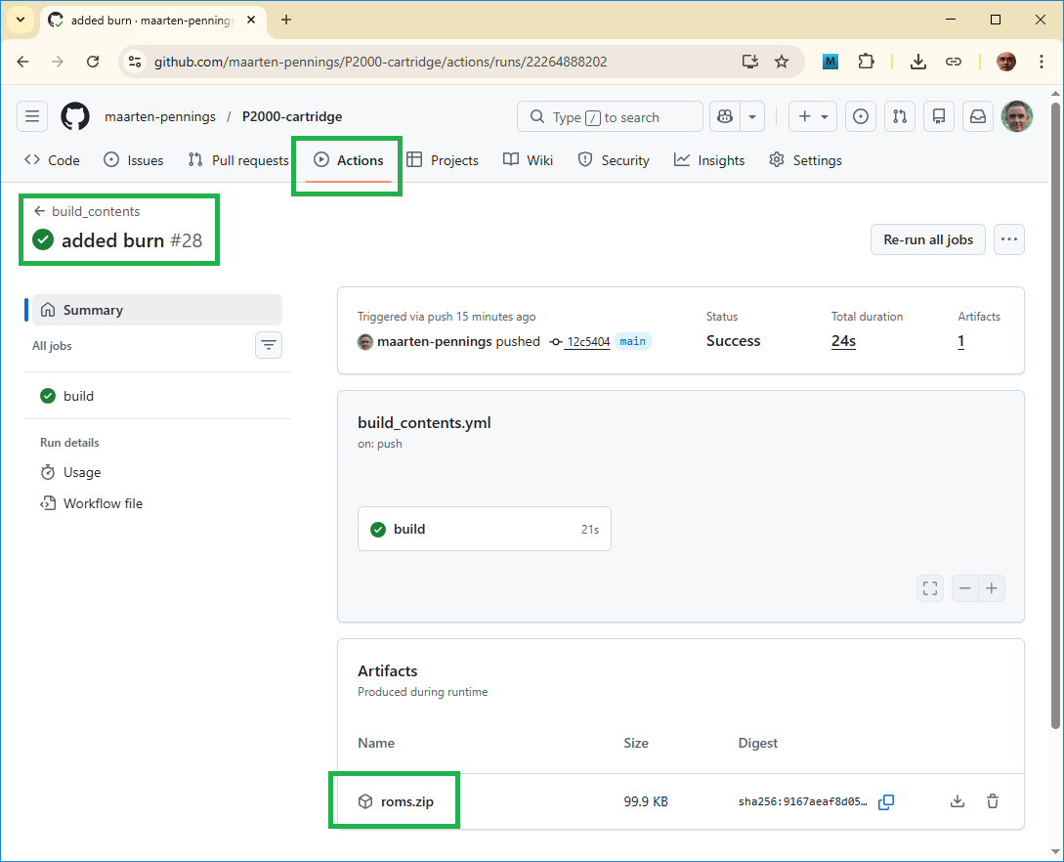
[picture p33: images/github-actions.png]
GitHub actions dashboard


It contains the compiled contents (.bin). It also contains the .afp files of all rom; from contents.bin,
but also from all stock roms.

## Burning

The shell script `burn.cmd` runs the `burn.py` on all 8 `.afp` files, effectively creating 
a multi ROM containing 8 cartridges.

The figure below shows an overview of the tools (Python scripts, 
shell script, makefile) in the process flow:

Flow overview

(end)

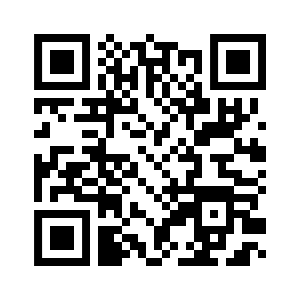
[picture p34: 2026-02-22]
images/qr-repo.png

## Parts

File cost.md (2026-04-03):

# P2000-cartridge - Cost

This file documents the cost made for a Philips P2000T cartridge.
Also listed is the cost for making a flash tool ("AFP" or Arduino Flash Programmer).

## Cartridge 

Needed to purchase components, the PCB and casing.

### Cartridge components

All components were ordered from AliExpress.
One cartridge needs these.

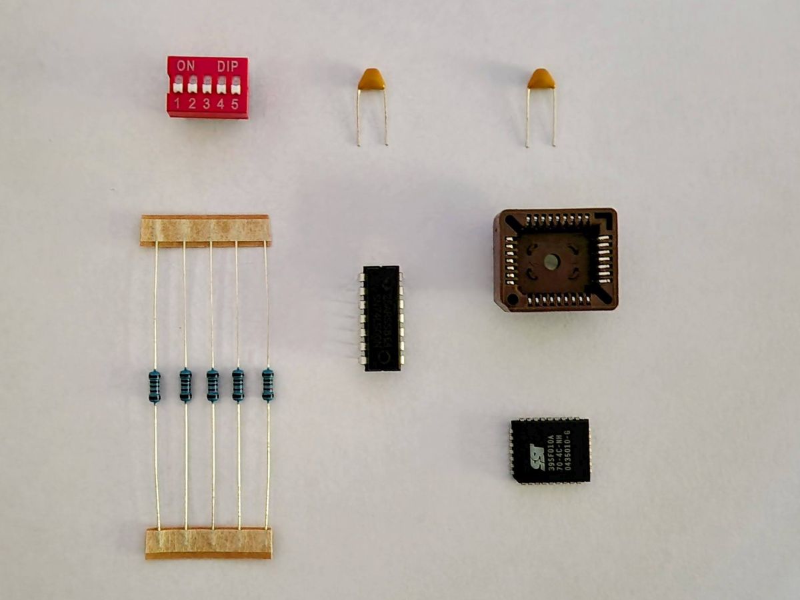
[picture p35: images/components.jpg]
Components


Observe that I ordered SST39SF010A memories. These are 1Mbit or 128kB which holds 8 ROMs (of 16kB).
The PCB can also handle SST39SF020A and SST39SF020A memories (for 16 or even 32) ROMs.
These PCBs will have SST39SF010A, so I first bought 3-throw dip switches, but
later decided to mount 5-throw switches. I also found out I ran out of capacitors, so 
I later bought a bag 100nF.

I ordered components for 10 cartridges.

  | Description       | Quantity  |     Cost | Link                                                        |
  |:------------------|----------:|---------:|:-----------------------------------------------------------:|
  | Resistor 10kΩ     | 50+  5×10 |    €1.19 | [🔗](https://nl.aliexpress.com/item/32952657927.html)       |
  | PLCC32-DIP socket |        10 |    €3.12 | [🔗](https://nl.aliexpress.com/item/33056827347.html)       |
  | DIPswitch 3 wide  | 10+     0 |    €2.14 | [🔗](https://nl.aliexpress.com/item/4001127324718.html)     |
  | PLCC32 to DIP32   |         1 |    €1.62 | [🔗](https://nl.aliexpress.com/item/1005006221329883.html)  |
  | SST39SF010A (mem) |        10 |    €6.39 | [🔗](https://nl.aliexpress.com/item/1005008535405486.html)  |
  | SN74LS00N (4×NAND)|        10 |    €2.43 | [🔗](https://nl.aliexpress.com/item/1005002328900896.html)  |
  | Shipping 1st order|         1 |    €0.00 |                                                             |
  | DIPswitch 5 wide  |        10 |    €2.16 | [🔗](https://nl.aliexpress.com/item/4001127324718.html)     |
  | Capacitor 100nF   | 80+  2×10 |    €1.79 | [🔗](https://nl.aliexpress.com/item/1005010370389462.html)  |
  | Shipping 2n order |         1 |    €0.00 |                                                             |
  | **Total**         |           |**€20.84**| [🔗](images/invoice-aliexpress.png)                         |

### Cartridge PCB

I ordered 10 [PCBs](pcb).

Components

  | Description        | Quantity |     Cost | Link                            |
  |:-------------------|---------:|---------:|:--------------------------------|
  | PCBs               |       10 |   €4.22  |                                 |
  | Shipping           |        1 |   €9.23  |                                 |
  | Import Taxes (21%) |        1 |   €2.83  |                                 |
  | Payment fee        |        1 |   €0.42  |                                 |
  | **Total**          |          |**€16.70**| [🔗](images/invoice-jlcpcb.png) |

### Cartridge case

I ordered 2 casings (top and bottom white and top and bottom black) with slow shipping.

Casing

  | Description        | Quantity |      Sub |     Cost | Link                            |
  |:-------------------|---------:|---------:|---------:|:--------------------------------|
  | Top black          |        1 |   €3.38  |          |                                 |
  | Bottom black       |        1 |   €4.14  |          |                                 |
  | **Complete Black** |        1 |          |   €7.52  |
  | Top white          |        1 |   €1.82  |          |                                 |
  | Bottom white       |        1 |   €2.22  |          |                                 |
  | **Complete White** |        1 |          |   €4.04  |
  | Shipping           |        1 |          |   €8.78  |                                 |
  | Import Taxes (21%) |        1 |          |   €4.27  |                                 |
  | **Total**          |          |          |**€24.61**| [🔗](images/invoice3Dprint.png) |

## Arduino Flash Programmer

Instead of buying a flash programmer, I made one myself.
I needed to purchase components and the PCB.

### AFP components

The Arduino Flash Programmer PCB can program the SST39SF010A memories.
I decided to make 2.

  | Description       | Quantity  |     Cost | Link                                                        |
  |:------------------|----------:|---------:|:-----------------------------------------------------------:|
  | Capacitor 100nF   | re-used   |    €0.00 | [🔗](https://nl.aliexpress.com/item/1005010370389462.html)  |
  | ZIF socket        |         2 |    €2.20 | [🔗](https://nl.aliexpress.com/item/1005006117085994.html)  |
  | Arduino Nano      | 1+      2 |    €6.08 | [🔗](https://nl.aliexpress.com/item/1005007392605300.html)  |
  | PLCC extractor    |         1 |    €1.89 | [🔗](https://nl.aliexpress.com/item/1005007532973884.html)  |
  | SN74HC595         | stock 2×2 |        ? |                                                             |
  | Shipping          |         1 |    €0.00 |                                                             |
  | **Total**         |           |**€10.17**|                                                             |

### AFP PCB

I ordered 5 PCBs (minimum order quantity) with slow shipping.

Components

  | Description        | Quantity |     Cost | Link                            |
  |:-------------------|---------:|---------:|:--------------------------------|
  | PCBs               |        5 |   €1.69  |                                 |
  | Shipping           |        1 |   €1.27  |                                 |
  | Import Taxes (21%) |        1 |   €0.63  |                                 |
  | **Total**          |          | **€3.59**| [🔗](flasher/pcb/order.png)     |

## Total 

The total cost of the project, i.e. a summary of the tables above.

  | Description          | Quantity |       Cost |
  |:---------------------|---------:|-----------:|
  | Cartridge components |       10 |    €20.84  |
  | Cartridge PCBs       |       10 |    €16.70  |
  | Cartridge casing     |        2 |    €24.61  |
  | AFP components       |        2 |    €10.17  |
  | AFP PCBs             |        2 |     €3.59  |
  | **Total**            |          |  **€75.91**|

(end)

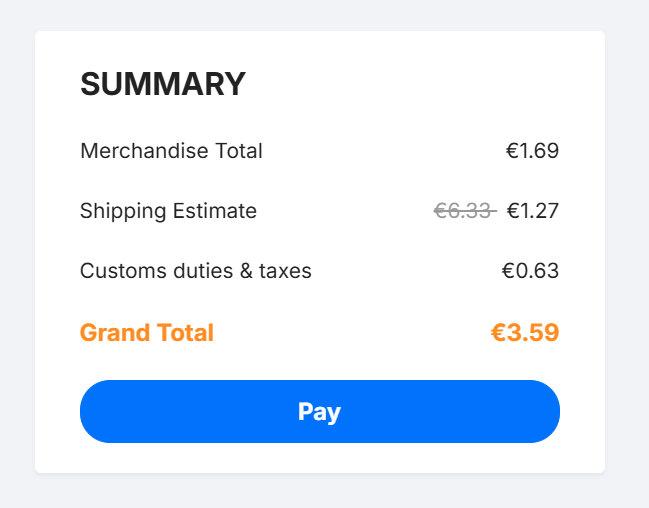
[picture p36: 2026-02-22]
flasher/pcb/order.png

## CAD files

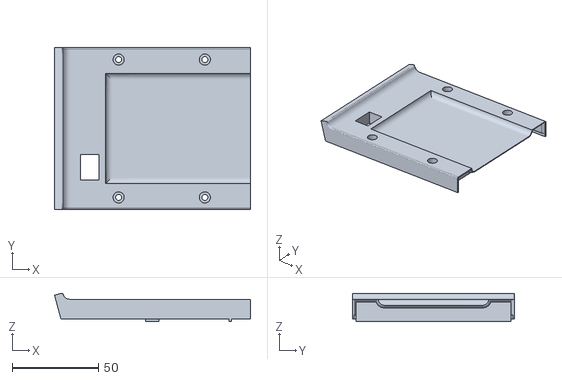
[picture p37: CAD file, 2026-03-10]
case/P2000-cartridge-top1.5mm.stl
113.7 x 94.0 x 16.5

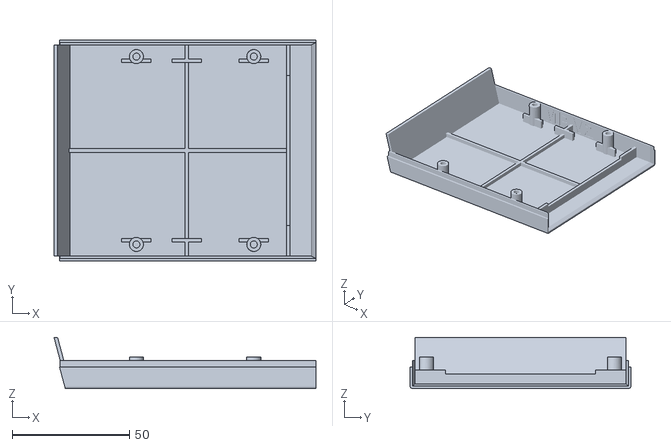
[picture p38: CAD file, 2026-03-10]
case/P2000-cartridge-bottom.stl
111.6 x 94.0 x 21.8

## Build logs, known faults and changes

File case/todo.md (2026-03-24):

# Todo

- The socketed IC still hits the case.
  We can not make the case thicker.
  Suggested is to put a slant on the PCB support ribs.

- The screw holes need improvement.
  Maybe just recessed holes in the front and hex gaps at the back.

- The front has 5 texture lines.
  They make the casing thin at that spot.
  Suggested is to add an extra layer on the inside.

(end)

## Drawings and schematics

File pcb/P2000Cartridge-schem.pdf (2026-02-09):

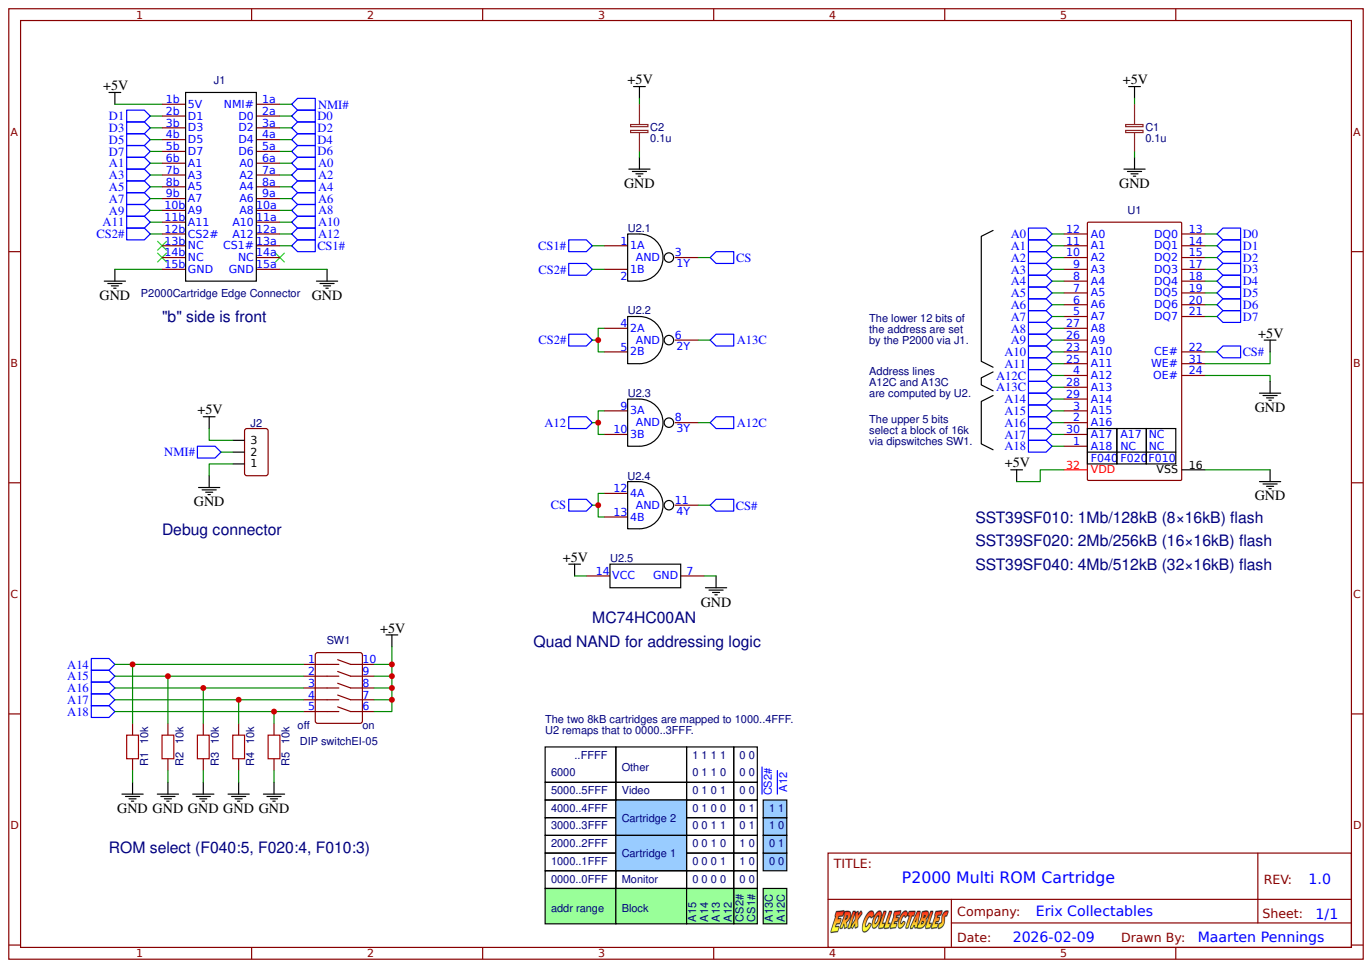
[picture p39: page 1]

GND 15a GND 15b NC 14b NC 13b CS2# 12b A11 11b A9 10b A7 9b A5 8b A3 7b A1 6b D7 5b D5 4b D3 3b D1 2b 5V 1b

The lower 12 bits of
the address are set
by the P2000 via J1.

Quad NAND for addressing logic

The two 8kB cartridges are mapped to 1000..4FFF.
U2 remaps that to 0000..3FFF.

GND GND GND GND GND

Drawn By: Maarten Pennings

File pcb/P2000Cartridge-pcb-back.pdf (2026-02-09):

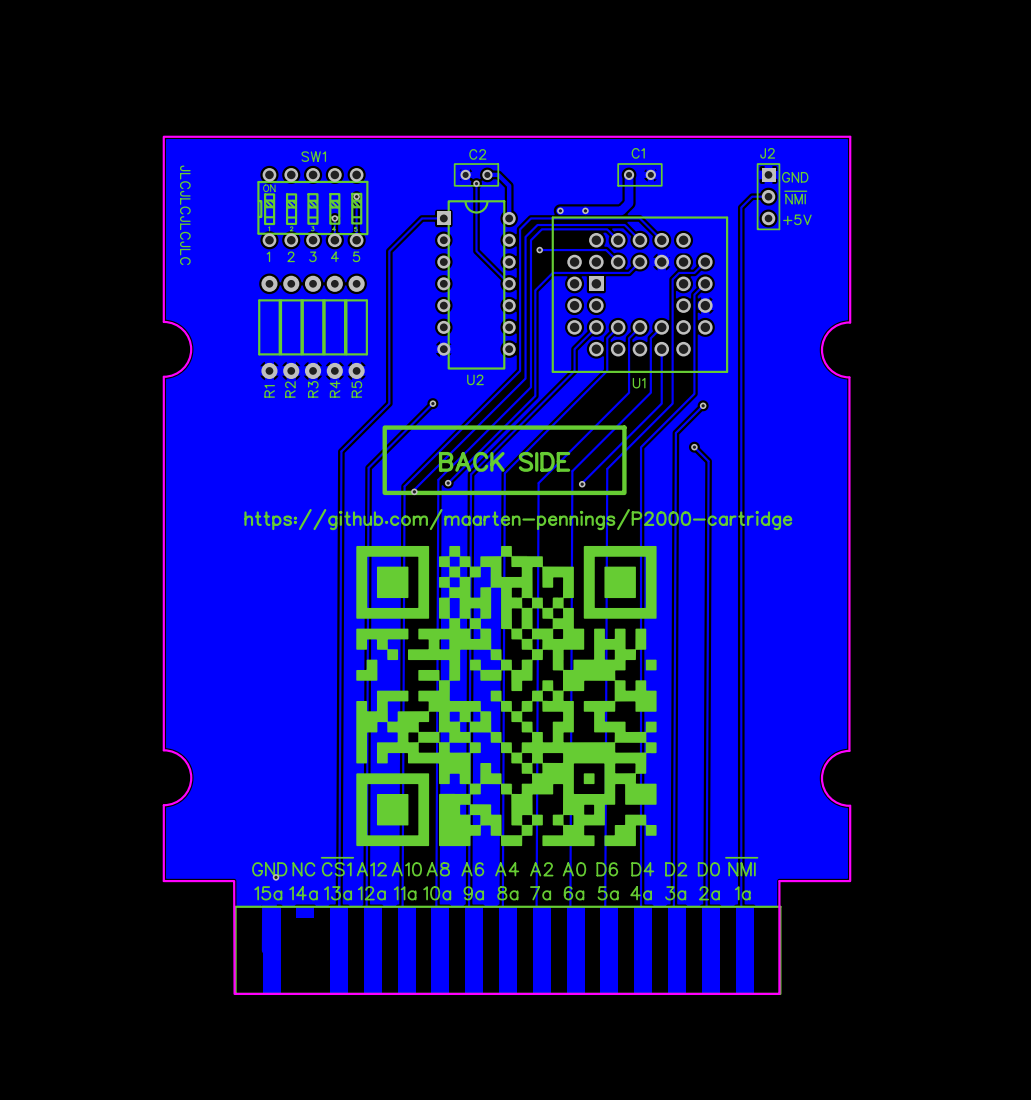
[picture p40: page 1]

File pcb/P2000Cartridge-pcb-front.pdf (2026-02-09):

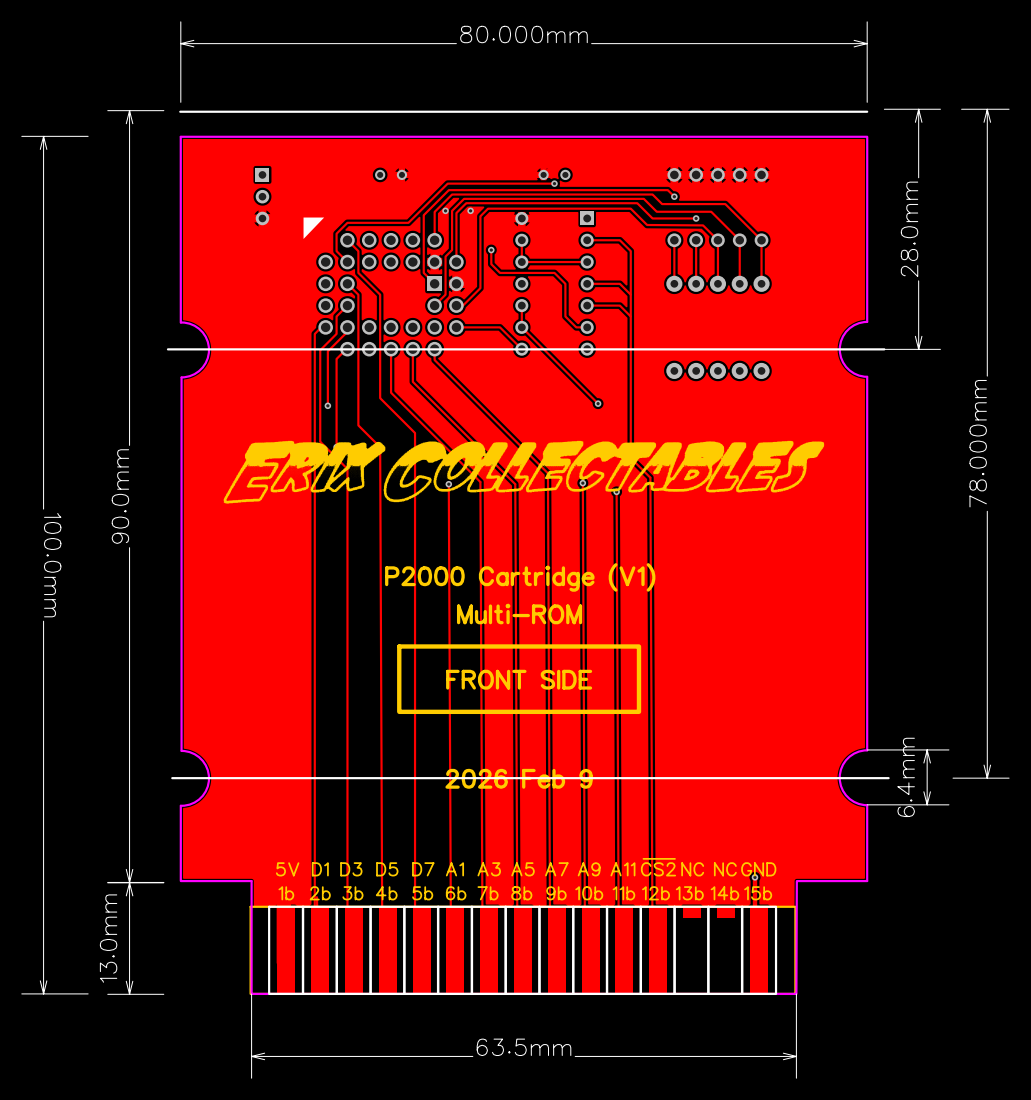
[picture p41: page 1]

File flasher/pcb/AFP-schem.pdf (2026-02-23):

# DATA2 CLK LATCH

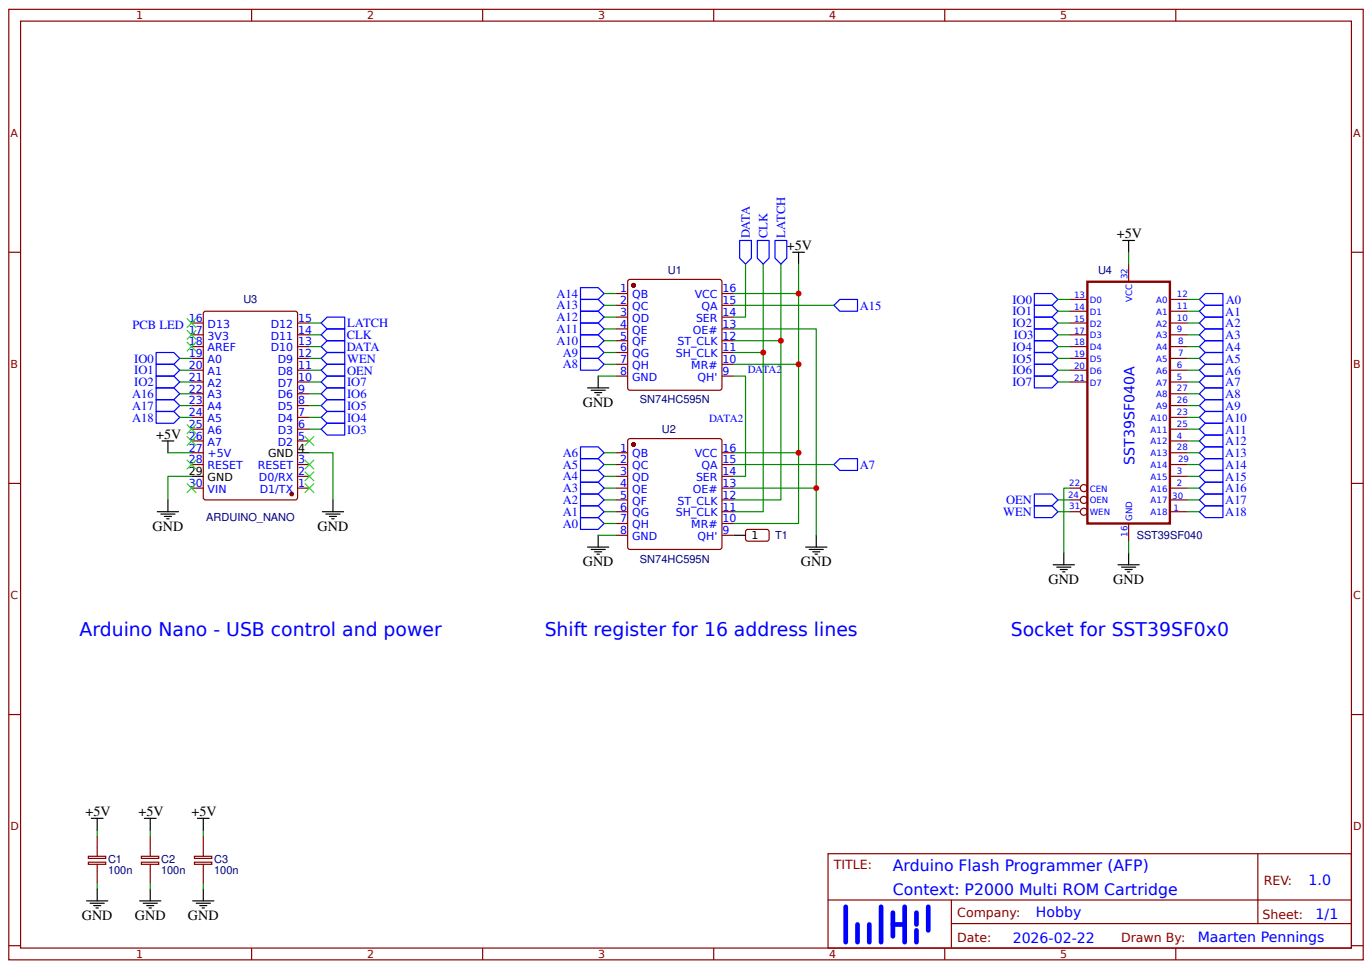
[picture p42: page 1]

Context: P2000 Multi ROM Cartridge

Drawn By: Maarten Pennings

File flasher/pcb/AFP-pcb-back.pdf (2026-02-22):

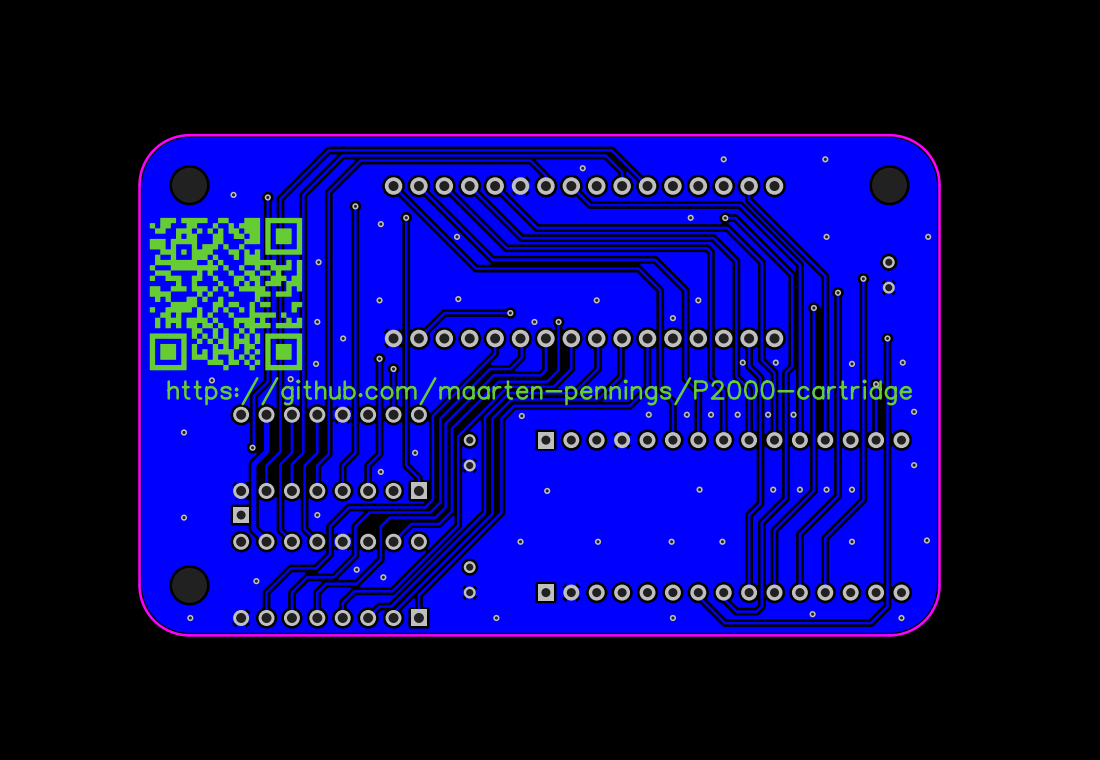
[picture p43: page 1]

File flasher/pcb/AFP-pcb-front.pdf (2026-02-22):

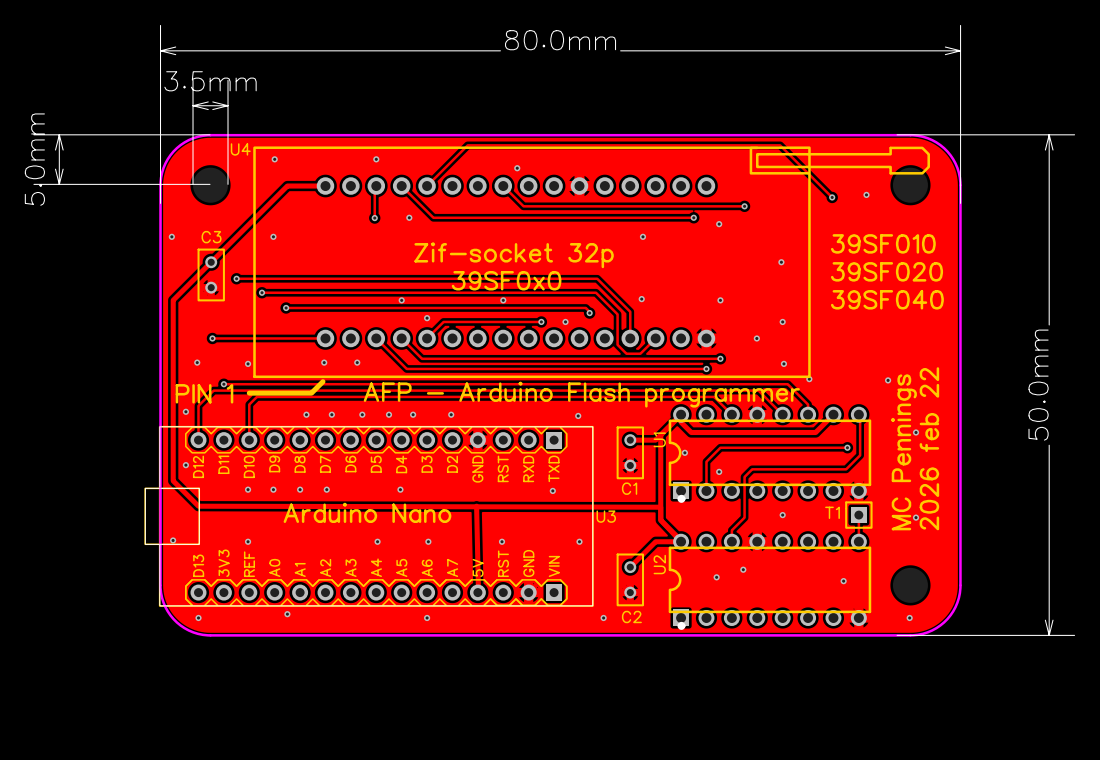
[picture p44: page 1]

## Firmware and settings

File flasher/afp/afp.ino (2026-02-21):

// afp.ino - Arduino Flash Programmer (for the 39SF010, 39SF020, and 39SF040)
#include "drv.h"      // drv_init()
#include "cmd.h"      // https://github.com/maarten-pennings/cmd (written on v8.2.3)
#include "cmdinfo.h"  // cmdinfo_register()
#include "cmdflash.h" // cmdflash_register()
#include "cmdread.h"  // cmdread_register()
#include "cmderase.h" // cmderase_register()
#include "cmdwrite.h" // cmdwrite_register()
#include "afp.h"      // AFP_LONGNAME


static void cmds_register() {
  cmdecho_register();
  cmderase_register();
  cmdflash_register();
  cmdhelp_register();
  cmdinfo_register();
  cmdread_register();
  cmdwrite_register();
  Serial.print( F("cmds : init\n") );
}


void setup() {
  Serial.begin(115200, SERIAL_8N1);
  Serial.print( F(AFP_BANNER) );
  Serial.print( F(AFP_LONGNAME) ); Serial.print( F(" - version ") ); Serial.print( F(AFP_VERSION) ); Serial.print("\n\n");

  drv_init();
  cmd_init();
  cmds_register();
  Serial.print("\n");

  Serial.print( F("Type 'help' for help\n") );
  cmd_prompt();
}


void loop() {
  cmd_pollserial();
}

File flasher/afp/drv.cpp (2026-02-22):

// drv.cpp - driver for the 39SF010, 39SF020, and 39SF040 flash chips
// Inspiration: https://github.com/slu4coder/SST39SF010-FLASH-Programmer


#include <Arduino.h>
#include <stdint.h>
#include "drv.h"


// This driver maintains two invariants
// This hold between function calls, but are maybe "violated" within a function
// + Flash-invariant (port B bits 0,1)
//   - WEN=1 (write disabled)
//   - OEN=1 (output disabled)
// + Shift-invariant (port B bits 3,4)
//   - CLK=0
//   - LAT=0


// We have a slightly confusing terminology:
// - The flash chip (39SF0x0) has up to 19 address lines (A0..A18)
// - The flash chip (39SF0x0) has precisly 8 io (data) lines (IO0..IO7).
// We use IO3 instead of D3, because D3 is a GPIO name of an Arduino pin.
void drv_init() {
  // This driver uses PORTX, DDRX, and PINX instead of digitalWrite() etc because of the speed.

  // D7  D6  D5  D4  D3  D2  D1  D0  (Arduino pin num)
  // PD7 PD6 PD5 PD4 PD3 PD2 PD1 PD0 (ATMEGA328 port/pin)
  // IO7 IO6 IO5 IO4 IO3  -   -   -  (PCB: flash data pins)
  PORTD = 0b00000000;
  DDRD  = 0b00000000;

  //  -   -  D13 D12 D11 D10 D9  D8  (Arduino pin num)
  //  -   -  PB5 PB4 PB3 PB2 PB1 PB0 (ATMEGA328 port/pin)
  //  -   -  LED LAT CLK DAT WEN OEN (PCB: control)
  PORTB = 0b00000011; // WEN=HIGH, OEN=HIGH
  DDRB  = 0b00111111; // bits to outputs (except unused ones)
  // flash and shift invariant established (WEN=1, OEN=1, CLK=0, LAT=0)

  // A7  A6  A5  A4  A3  A2  A1  A0  (Arduino pin num alt)
  //  -   -  D19 D18 D17 D16 D15 D14 (Arduino pin num)
  //  -   -  PC5 PC4 PC3 PC2 PC1 PC0 (ATMEGA328 port/pin)
  //  -   -  A18 A17 A16 IO2 IO1 IO0 (PCB: flash address and data pins)
  PORTC = 0b00000000;
  DDRC  = 0b00111000;  // address lines output

  Serial.print( F("drv  : init\n") );
  // flash and shift invariant
}


// Shortcuts for the control lines (in port B)
#define SET_OEN(state)    bitWrite(PORTB, 0, state)   // output enable pin flash chip (high for write, low for read)
#define SET_WEN(state)    bitWrite(PORTB, 1, state)   // write  enable pin flash chip (low for write, high for read)
#define SET_DAT(state)    bitWrite(PORTB, 2, state)   // Data  line of 74HC595 shift register: DAT (aka SER)
#define SET_CLK(state)    bitWrite(PORTB, 3, state)   // Clock line of 74HC595 shift register: CLK (aka SRCLK or SH_CLK)
#define SET_LAT(state)    bitWrite(PORTB, 4, state)   // Latch line of 74HC595 shift register: LAT (aka RCLK or ST_CLK)
#define SET_LED(state)    bitWrite(PORTB, 5, state)  // Control the LED integrated on the Nano board


// Post condition of these macros is flash and shift invariant (assuming pre condition is also both)
#define PULSE_WEN()       do { SET_WEN(LOW); SET_WEN(HIGH); } while(0)
#define PULSE_CLK()       do { SET_CLK(LOW); SET_CLK(HIGH); } while(0)
#define PULSE_LAT()       do { SET_LAT(HIGH); SET_LAT(LOW); } while(0)


// Before a read or write operation, the address pins of the flash chip must be set.
// These pins are spread over 3 pins in port C (A18..A16) and 16 via external shift registers (A15..A0).
// This function sets all 19 address lines (512k range).
// The external shift register is wired as LSB first.
void drv_addr_set(uint32_t addr) {
  for( uint8_t i=0; i<16; i++) {
    bitWrite(PORTB, 2, addr & 1);
    PULSE_CLK();
    addr = addr>>1;
  }
  PULSE_LAT();
  PORTC = (PORTC & 0b11000111) | ((addr<<3) & 0b111000); // Set three MSB of addr
  // flash and shift invariant (CLK and LAT pulsed)
}


// The data or IO pins (IO7..IO0) are spread of port C (3 LSBs) and port D (5 MSBs).
// When reading from the flash, we need to configure these pins as tristate input.
void drv_io_cfgread() {
  // Note the &=
  DDRC  &= 0b11111000; // Three LSBs IO2/IO1/IO0 to input (0)
  PORTC &= 0b11111000; // When input, PORTC controls tristate (0) or pullup (1); switch inputs to tristate
  DDRD  &= 0b00000111; // Five MSBs IO7/IO6/IO5/IO4/IOD3 to input (0)
  PORTD &= 0b00000111; // When input, PORTC controls tristate (0) or pullup (1); switch inputs to tristate
  // flash and shift invariant (port B not touched)
}


// The IO pins (IO7..IO0) are spread of port C (3 LSBs) and port D (5 MSBs).
// When writing to the flash, we need to configure these pins as output.
void drv_io_cfgwrite() {
  // Note the |=
  DDRC |= 0b00000111; // Three LSBs IO2/IO1/IO0 to output (1)
  DDRD |= 0b11111000; // Five MSBs IO7/IO6/IO5/IO4/IOD3 to input (0)
  // flash and shift invariant (port B not touched)
}


// Once the data aka IO pins are configured for input - with drv_io_cfgread()
// this function reads the values on the pins and assembles them into a byte.
// Note, OEN must be pulled low before the flash chip puts the data on the pins.
#define drv_io_get()         ( (PIND & 0b11111000) | (PINC & 0b00000111) )


// Once the data aka IO pins are configured for output - with drv_io_cfgwrite()
// this function writes the bits from io to the various pins.
// Note, this puts signals on the data aka IO pins of the flash, it does not necesarily write to flash.
// For this flash needs to be prepared ("byte-program sequence"), see drv_io_write() for that.
void drv_io_set(uint8_t io) {
  PORTC = (PORTC & 0b11111000) | (io & 0b00000111); // Three LSBs IO2/IO1/IO0 written
  PORTD = (PORTD & 0b00000111) | (io & 0b11111000); // Five MSBs IO7/IO6/IO5/IO4/IOD3 written
  // flash and shift invariant (port B not touched)
}


void drv_io_read(uint32_t addr, uint8_t * io, uint8_t size) {
  drv_io_cfgread();
  SET_OEN(LOW);
    for( uint32_t a=addr; a<addr+size; a++ ) {
      drv_addr_set(a);
      *io= drv_io_get();
      io++;
    }
  SET_OEN(HIGH);
  // flash and shift invariant (OEN restored)
}


#define MSB(x) ((x)&128)
// This functions writes data `io` to address `addr` in the flash.
// It prepares the flash for the write operation ("byte-program sequence"), then writes, then waits till write completes.
// Returns true iff write completes in time (~20us).
// Writing `mem[addr]=io` actually means "and with `mem[addr]&=io`, so only 0 bits are created.
// Before writing typically erase the sector of entire chip.
bool drv_io_write(uint32_t addr, uint8_t io) {
  SET_LED(HIGH);
  // Write the byte-program sequence
  drv_io_cfgwrite();
  drv_addr_set(0x5555); drv_io_set(0xaa); PULSE_WEN();
  drv_addr_set(0x2aaa); drv_io_set(0x55); PULSE_WEN();
  drv_addr_set(0x5555); drv_io_set(0xa0); PULSE_WEN();
  // Write the byte
  drv_addr_set(addr);   drv_io_set(io);   PULSE_WEN();
  // Poll for completion
  drv_io_cfgread();
  SET_OEN(LOW);
    uint8_t time=0; while( (MSB(drv_io_get())!=MSB(io)) && (time<100) ){ time++; delayMicroseconds(1); } // time ~20us
  SET_OEN(HIGH);
  //Serial.print("byte write "); Serial.print(time); Serial.print("us\n");
  SET_LED(LOW);
  // Put other signal out, so that a verifying read (with no flash chip present) will not succeed
  drv_io_set(~io);
  return time<50;
  // flash and shift invariant (WEN pulsed, OEN restored)
}
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

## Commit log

2026-02-09 adding pcb design
2026-02-15 Arduino flasher PoC
2026-02-16 flasher schematics
2026-02-18 Erase map improved, added LED to drv for mofifications
2026-02-18 Added 'write' command, unified ERROR msgs, added more @-support
    [afp.ino, cmderase.cpp, cmdflash.cpp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]
2026-02-18 Fixed bug in elapsed time
    [cmdwrite.cpp]
2026-02-19 first PCB
2026-02-20 PCB re-design suggestions
    Added notes on PCB design improvements and considerations.
2026-02-21 clean up make process
    - renamed res to generated
    - fixed help 'flash' command
    - fixed help all py scripts
    [afp.py, cmdflash.cpp, pad.py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]
2026-02-22 added afp pcb
2026-02-23 updated afp/pcb
2026-03-05 firmware 1.0a (Fixed some help texts)
    [cmderase.cpp, cmdread.cpp, cmdwrite.cpp]
2026-03-05 Add flasher PCB
2026-03-10 Added 3D printing
    [P2000-cartridge-bottom-extprint-black.stl, P2000-cartridge-bottom-extprint-white.stl, P2000-cartridge-top1.5mm-extprint-black.stl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]
2026-03-20 added AFP manual (and fixed a bug)
    [cmdread.cpp]
2026-03-24 Create todo.md for case design notes
    Add a todo list for case design improvements
2026-04-03 Correct 'Android' to 'Arduino' in cost.md
